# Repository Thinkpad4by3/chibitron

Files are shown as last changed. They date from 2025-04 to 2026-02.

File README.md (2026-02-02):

# chibitron
Chibitron is a Electrostatic CRT driver design built to solve the issues I've had with many of the other designs seen elsewhere on the internet. 

## Goals of the Project
* Fully Open Source HW/FW
* Compatible with as many CRTs as possible, as small as a 1EP1 or as big as a 7JP4.
* Single supply 12V input, with all necessary voltages generated on board.
* Onboard vector generation ability
* Ability to play Oscilloscope music with no extra equipment required.
* Built out of entirely currently stocked parts, using more common parts, when possible.

## Design of the system
Design of the system is designed around a two-part architecture. The main board provides all the required voltages to run the tube, mainly A2/A3/Focus control. This provides the main power for the electron gun, and can be adjusted from 400 - 2000V on mono-accelerator tubes (A2), or optionally boosted with another 400-2000V on post-deflection accelerator tubes(A2+A3). Total combined acceleration maxes out at 4kV which is sufficient for a very bright, very sharp image even on the most demanding of tubes. Filament voltage is supplied through a fully isolated 6.3V source, and focus is derived off A2 through a class-A amplfier. 

The 2nd board is the deflection board, which consists of all the required components to take any sort of vector control X/Y signal and amplify it to the +/- 150V required to move the beam around. This board is compatible with almost every type of ES-CRT, including single ended deflection type tubes. All plates are driven by 300Vpk-pk 500KHz bandwidth amplifiers, where gain/offset can be used to control picture size, and neutral voltage can set for astigmatism. Amplifiers are of a class-AB variety, and are closed loop for minimal distortion, and are powered by their own local bi-polar power supplies. 

Z-axis control is currently a WIP, but is going to be fully DC coupled. 

Currently, system has been tested with over a dozen CRTs, all showing clear and bright pictures with excellent clarity and brilliance. Tubes can be swapped in and out quickly with only minor tweaks to the board trimmer potentiometers. 

## CRT terminology:
Electrostatic CRT: Type of cathode-ray tube that uses capacitive plates to steer an electron beam with electric field instead of magnetic field  
H (Heater): Heater, used to heat cathode and cause thermionic emission of electrons  
K (Cathode): Cathode of tube, creates free electrons  
G1 (Grid): Grid control voltage, negatively biased from cathode to control electron beam current (and therefore beam brightness)  
A1 (Focus): Focus control voltage, used to create an electron lens, focusing beam to tight point on the screen surface  
A2 (Accelerator): Main anode for accelerating electrons towards screen   
Dx (Deflection): Plates numbered 1-4 for deflecting beam in X-Y direction. 1-2 are pair, 3-4 pair, with 3-4 usually being the more sensitive pair  
    -some tubes tie D1/D3/A2 together, known as single-ended deflection  
Astigmatism: generated through an offset between Dx neutral voltage and the A2 voltage.  
A3 (Post-deflection Accelerator): Anode inside the bell of the CRT which will accelerate electrons further after deflection. Used for increasing brightness without affecting deflection sensitivity.  

Phosphor: coating on the front of the tube that glows when struck with electrons. Comes in many varieties and colors; most commonly, green.   

Tube types: many US-made tubes follow a very simple naming scheme. For example, the 3BP1.  

3 -> 3" display  
B -> tube series (successor to 3AP1)  
P1 -> P1 phosphor designation, being a green medium persistence type.  

## Current files:
High Voltage supplies:
- main_supply: 1st generation 1000V
- main_supply_2: 1st generation 1500V + FILTERED
- main_supply_3: 2nd generation 2kV + 2kV 
- main_supply_3_revised: 2nd generation 2kV + 2kV BUG FIXED

Deflection:
- deflection_board: 1st generation ANALOG
- deflection_board_2: 2nd generation ANALOG
- deflection_board_3: 3rd generation DIGITAL 
- deflection_board_4: 3rd generation ANALOG
- deflection_board_5: 4th generation ANALOG + COMPOSITE

Check out the README under each folder for more information on the individual. 

## Currently tested working tubes:
3ASPx
3BPx
3JPx
3FPx
3RPx
5BPx
5UPx
5DEPx
5" unknown DuMont rectangular, medium base.
5XPx-B
7VPx

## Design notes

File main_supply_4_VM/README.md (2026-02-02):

## CRT High Voltage Gen.2 

## Status
- Completed, succeeded by main_supply_3_revised
- I would not recommend building this board

##  Design & Architecture 
The architecture was re-thought out from scratch over the previous supply. With the LM5180, they tended to work quite well, however they did have a bit of a major downside....regulation. Under extremely light load, the voltage would soar, and under very heavy load or it would tend to compensate by increasing the output voltage. Given the method of regulation is feedback sensing through the primary side, and high ratio step-up transformers are known for poor leakage inductance, the sensing ability of the converter could be quite poor at times. (See notes on Gen.1 V2 for more info on this)

(Mention the lack of a good method of adjustment due to the Rfb being a single resistor)

The new design uses an LM5155 and a far more conventional topology. The filament was powered through a TL431 regulated isolated flyback converter, and the A2/A3 generation was done through non-isolated ground referenced converters. A2 was referenced to ground, so the A2 supply generated the cathode potential at -400 - 2000V, and A3 was just the positive copy of A2. The main HV supplies use the NA5920-ALD, the only >1:10 ratio transformer available at the moment that is 

1) easily available
2) supports a >1000V HiPOT rating.

You might ask how I planned on getting 2000V out of a (barely) 1000V transformer. Well I'm going to use a voltage multiplier to just multiply the output by 3X. Seems like a good idea....cockroft-walton multipliers have been a proven choice of high-voltage generation for nearly a century. Well, we will get back to this in a bit. The exact topology follows the "boost mode style" found in a few LiDAR supplies and the like, which means that the charge pump caps are seperate from the filter caps, and the filter caps are larger. Otherwise, it operates the same way. Rough calculations say that 3x multiplier @ 2000V should keep the primary side at ~700V even at max voltage, should be fine for a 1500Vrms rated transformer. Primary side spiking thanks to the large 1:24 ratio would be kept at a meager 30V which would allow the choice of some more common low-voltage FETs.

Focus Amplifier was a somewhat odd design. As found on previous designs, the standard focus ladder stack was limiting for larger tubes. The highest voltage potentiometer easily available is 500V, and some larger tubes (7JP/7VP series) takes nearly 1kV on A1.

Revised from the LM5180, now uses the LM5155

designed to be SSR regulated, which was for better performance

higher voltage, more power

focus amplfiier was cursed, but it did work & iso-amp

moving the controls to the primary side for safety. 

opto feedback stuff 

NA5920-ALD transformer

## Troubleshooting & Bring-up 
lol SO MANY PROBLEMS

reversed problem with the opto-isolator.

missing soft-start

improperly UVLO spec'd resistors

- [ ] Wrong value resistors for the feedback chain for 400-2.1kV - A2
- [ ] Increase soft-start capacitance
- [ ] Transformer wrong: switch to Wurth 10:1 part
- [ ] MOSFET too low voltage: need >200V part
- [ ] Fix layout to not have GND overlapping underneath transformer
- [ ] Add RC filtering to A2,A3 + LC filtering to Filament
- [ ] Change TLV314 to TLV237, check >6.8V operation
- [ ] Fix the 20 ohm resistors in the VM’s to be in the correct spot
- [ ] Add soft start to filament supply 
- [ ] Capacitively couple feedback -> test this (only on A3)
- [ ] Change the RC filtering?? 2/2n + 100ohm & 1k R slope comp.
- [ ] Change connectors and remove focus amp from power supply side.
- [ ] Re-layout and silkscreen
- [ ] Add large input cap and filtering 
- [x] UVLO resistors configured incorrectly to disable on low-voltage - 10k lower
- [x] Fix diode on filament to be Schottky not HV rectifier
- [x] Add 220n + 2k resistor on A2
- [x] Add interlock if no power to op amp -> no A2 supply?
- [x] ADD POWER TO THE FUCKING AMPLIFIER FOR A2 FEEDBACK
- [x] Wrong sense resistor values for Current sense - 0.02ohm
- [x] Wrong value resistors for the feedback chain for 400-2.1kV - A3
- [x] Opto feedback wired up wrong - fix

## Learnings
really need to revisit how amplifiers works 

need to severely filter my output 

flybacks have sort of unregulated voltage

amp design seems good, continue with. 

8pF = slow feedback. will continue to monitor.

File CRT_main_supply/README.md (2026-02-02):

## CRT HV Supply Gen.1 V1

## Status
- Completed, succeeded by CRT_main_supply_2
- I would not recommend building this supply

##  Design & Architecture 
Uses the LM5180 Primary Side Regulated flyback controller. This was the easiest control to implement, given the original prototype was based on the LT8304-1 controller, which is the Analog Design variant of the same IC. The following reference design was used as my starting point for an inital prototype made a few months prior. This proved to be enough to get some life into a 3BP1, so I continued forward with that. I used the same 0399-T208 transformer, rated for 1KV output at up to 15mA, which was great for availability when I started this project. 

The use of a PSR regulator was great since it eliminated the need for any output sense such as a TL431 or large resistor ladder, and made it quite easy to slap a few of them on for the A2, Filament & Grid drive all with one converter. The supply was biased such that the ground reference could be moved around as needed, for experimentation purposes. 

Focus and Brightness are controlled through resistor dividers between A2 and Cathode.

Otherwise, the overall design was quite simple, and would be further revised later. 

Link: https://www.analog.com/en/resources/technical-articles/1000-v-output-no-opto-isolated-flyback-converter.html

## Troubleshooting & Bring-up 
Main problem with bring-up on this was down to the LM5180's undiagnosed requirement for RC filtering on the primary side. Due to the large step-up ratio and leakage inductance within the transformer, ringing under load would go far above the >85V rating of the internal FET. This is less of a problem when used in a 1:1 or lower ratio, where the reflected voltage is more...reasonable. A 220p + 100 ohm resistor as suggested by the LT8304 ended up being a good solution to fix this ringing, however not before nuking about 10 of those LM5180s. Atleast they're more reasonably priced than the LT8304. 

Other major issue was that the Filament was tied to the -1500V rail instead of floating off the cathode. For the purposes of most tubes, this is not a problem. Most CRTs have a H-H-K arrangement, which means the cathode is indirectly heated, and can generally float within +/- 125V of the cathode. G1-cutoff should be no more than 100V from the cathode, so this is generally fine. However, on some tubes, they are tied H-HK where either the tube is directly heated and the cathode is the heater, or the tube has the two connections internally tied to save pin-count. Either way, given the goal of maximum compatibility, mandating a tied HK was necessary.

Supply was able to light up a 3BP1, at this point I did not have many tubes to test with and this was the only tube I felt safe to test with. It did provide a decent picture, albeit a bit fuzzy. Some of this was due to unfiltered switching noise from the HV supplies. At this point, it just lit up with a dot since deflection_amp has not been brought up yet. It was however, good enough to get through deflection_amp developed, and therefore served its purpose.

## Learnings
LM5180 has some issues, regulation isn't wonderful and didn't like starting up the main filament supplies. Filament took nearly 6 seconds to get to full voltage, and another 10 seconds for the tube to start conducting. 

Ground reference can be set to GND -> A2 is optimal.

H-HK filament biasing required.

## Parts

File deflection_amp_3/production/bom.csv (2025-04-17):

Designator | Footprint | Quantity | Value | LCSC Part #
C1, C11, C12, C2, C3, C4 | 0805 | 6 | 10u
C10, C9 | 0805 | 2 | 0.22u
C13, C14, C15 | 1812 | 3 | 1u
C16, C19, C20, C22, C24, C25, C26, C27, C28, C29, C30, C31, C44, C45, C46, C47 | 0603 | 16 | 0.1u
C17, C18 | 0603 | 2 | 15p
C21, C23, C7, C8 | 0603 | 4 | 1u
C32, C35, C38, C41 | 0603 | 4 | 2p
C33, C36, C39, C42, C5, C6 | 0603 | 6 | 1n
C34, C37, C40, C43 | 0603 | 4 | 39p
D1, D2, D3 | D_SOD-123F | 3 | D
D4, D5, D6, D9 | 0603 | 4 | LED
D7 | D_SOD-123 | 1 | 4.1V
D8 | D_SOD-123 | 1 | 11V
F1 | 0805 | 1 | 2A
J1 | USB_C_Receptacle_Palconn_UTC16-G | 1 | USB_C_Receptacle_USB2.0_14P
J2 | Molex_KK-396_5273-02A_1x02_P3.96mm_Vertical | 1 | POWER INPUT
J3 | PinHeader_1x03_P2.54mm_Vertical | 1 | OFFSET REFERENCE
J4 | Molex_KK-396_5273-05A_1x05_P3.96mm_Vertical | 1 | DEFLECTION OUT
L1, L2 | L_APV_APH0420 | 2 | 10u
Q1, Q11, Q14, Q16, Q17, Q19, Q22, Q24, Q25, Q27, Q3, Q30, Q32, Q6, Q8, Q9 | SOT-23 | 16 | FMMT458TA
Q10, Q12, Q13, Q15, Q18, Q2, Q20, Q21, Q23, Q26, Q28, Q29, Q31, Q4, Q5, Q7 | SOT-23 | 16 | FMMT558TA
R1, R2 | 0603 | 2 | 5.1k
R10, R9 | 0603 | 2 | 107k
R11 | 0603 | 1 | 14.3k
R12, R13, R3, R5, R8, R81, R82 | 0603 | 7 | 100k
R14 | 0603 | 1 | 162k
R15, R16 | 1206 | 2 | 22
R17, R19 | 1206 | 2 | 1Meg
R18 | 1206 | 1 | 12.7k
R20 | 1206 | 1 | 6.3k
R21, R25, R29, R30, R42, R43, R55, R56, R68, R69 | 0603 | 10 | 10k
R22, R84 | 0603 | 2 | 1k
R23, R24 | 0603 | 2 | 27.4
R26, R27, R32, R33, R35, R36, R37, R38, R39, R40, R45, R46, R48, R49, R50, R51, R52, R53, R58, R59, R61, R62, R63, R64, R65, R66, R71, R72, R74, R75, R76, R77 | 1206 | 32 | 2k
R28, R41, R54, R67 | 1206 | 4 | 200k
R31, R34, R44, R47, R57, R60, R70, R73 | 1206 | 8 | 5k
R4 | 0603 | 1 | 19.7k
R6, R7 | 0603 | 2 | 84.5k
R78, R79, R80, R83 | 0603 | 4 | 220
RV1, RV2, RV3, RV4, RV5 | Potentiometer_Bourns_3296W_Vertical | 5 | 100k
SW1 | SW_SPST_Omron_B3FS-101xP | 1 | RESET
SW2 | SW_SPST_Omron_B3FS-101xP | 1 | PROG
TP1 | TestPoint_Pad_1.0x1.0mm | 1 | SWCLK
TP2 | TestPoint_Pad_1.0x1.0mm | 1 | SWD
TP3 | TestPoint_Pad_1.0x1.0mm | 1 | GND
U1, U2 | SOT-23-5 | 2 | AP2205-ADJ
U10, U11, U12, U9 | TSOT-23-6 | 4 | LMH6639
U3, U4 | Analog_MSOP-12-16-1EP_3x4.039mm_P0.5mm_EP1.651x2.845mm | 2 | LT8365
U5 | SOIC-8_5.3x5.3mm_P1.27mm | 1 | W25Q128JVS
U6 | QFN-56-1EP_7x7mm_P0.4mm_EP3.2x3.2mm | 1 | RP2040
U7, U8 | SOIC127P599X175-8N | 2 | MCP4822
Y1 | Crystal_SMD_3225-4Pin_3.2x2.5mm | 1 | ABM8-272-T3

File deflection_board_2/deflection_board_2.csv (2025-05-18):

Reference | Value | Datasheet | Footprint | Qty | DNP
C1,C10,C15,C20 | 68p | QSCP251Q390G1GV001T | Capacitor_SMD:C_0603_1608Metric_Pad1.08x0.95mm_HandSolder | 4
C2,C9,C14,C19 | 2p | GRM1885C1H8R0DA01D | Capacitor_SMD:C_0603_1608Metric_Pad1.08x0.95mm_HandSolder | 4
C3,C4,C5,C6,C7,C8,C11,C12,C13,C16,C17,C18 | 0.1u | CL10E104KC8VPNC | Capacitor_SMD:C_0603_1608Metric_Pad1.08x0.95mm_HandSolder | 12
C21,C22 | 0.1u | CL10E104KC8VPNC | Capacitor_SMD:C_0603_1608Metric | 2
C23,C24 | 1u | C1608X7R1C105K080DC | Capacitor_SMD:C_0603_1608Metric | 2
C25,C26,C27,C30 | 10u | ~CL10A106KQ8NNNC | Capacitor_SMD:C_0603_1608Metric | 4
J1,J2,J3,J4 | Conn_01x03_Pin | ~ | Connector_PinHeader_2.54mm:PinHeader_1x03_P2.54mm_Vertical | 4
J5 | MAIN BOARD CONNECTOR | 0009652098 | Connector_Molex:Molex_KK-396_5273-09A_1x09_P3.96mm_Vertical | 1
J6,J7 | RCJ-011 | RCJ-011 | RCJ-011:CUI_RCJ-011 | 2
L1 | L | NRS4018T100MDGJ | Inductor_SMD:L_APV_ANR4018 | 1
Q1,Q2,Q7,Q8,Q9,Q11,Q14,Q16,Q17,Q19,Q22,Q24,Q25,Q27,Q30,Q32 | FMMT458TA | FMMT458TA | Package_TO_SOT_SMD:SOT-23 | 16
Q3,Q4,Q5,Q6,Q10,Q12,Q13,Q15,Q18,Q20,Q21,Q23,Q26,Q28,Q29,Q31 | FMMT558TA | FMMT558TA | Package_TO_SOT_SMD:SOT-23 | 16
R1,R11,R21,R31,R41,R42,R43,R44 | 2k | RMCF1206FT2K00 | Resistor_SMD:R_1206_3216Metric_Pad1.30x1.75mm_HandSolder | 8
R2,R12,R22,R32 | 200k | ERA-8AEB204V | Resistor_SMD:R_1206_3216Metric_Pad1.30x1.75mm_HandSolder | 4
R3,R9,R10,R16,R19,R20,R26,R29,R30,R36,R39,R40 | 1k | RNCP1206FTD1K00 | Resistor_SMD:R_1206_3216Metric_Pad1.30x1.75mm_HandSolder | 12
R4,R17,R27,R37 | 100 | ERJ-8ENF1000V | Resistor_SMD:R_1206_3216Metric_Pad1.30x1.75mm_HandSolder | 4
R5,R6,R13,R14,R23,R24,R33,R34,R59,R63 | 10k | RMCF0603JT10K0 | Resistor_SMD:R_0603_1608Metric_Pad0.98x0.95mm_HandSolder | 10
R7,R8,R15,R18,R25,R28,R35,R38 | 5k | RT1206FRE075KL | Resistor_SMD:R_1206_3216Metric_Pad1.30x1.75mm_HandSolder | 8
R45,R46 | 6.2k | RC0603JR-076K2L | Resistor_SMD:R_0603_1608Metric | 2
R47,R48 | 3.7k | RN73H1JTTD3701B25 | Resistor_SMD:R_0603_1608Metric | 2
R49 | 30.3k | RMCF0805FT30K0 | Resistor_SMD:R_0805_2012Metric | 1
R50,R52 | 10k | RR1220P-103-D | Resistor_SMD:R_0805_2012Metric | 2
R51 | 70.6k | RNCF0805BKE70K6 | Resistor_SMD:R_0805_2012Metric | 1
R53,R54 | 10k | RMCF0603JT10K0 | Resistor_SMD:R_0603_1608Metric | 2
R61,R65,R67,R69 | 1k | ERJ-3EKF1001V | Resistor_SMD:R_0603_1608Metric_Pad0.98x0.95mm_HandSolder | 4
R62,R66,R68,R70 | 2.2k | CRGCQ0603F2K2 | Resistor_SMD:R_0603_1608Metric_Pad0.98x0.95mm_HandSolder | 4
RV6,RV8 | 5k | 3296W-1-502LF | Potentiometer_THT:Potentiometer_Bourns_3296W_Vertical | 2
RV7,RV9 | 47k | 3296W-1-473LF | Potentiometer_THT:Potentiometer_Bourns_3296W_Vertical | 2
U1,U2,U3,U4 | LMH6639 | LMH6639 | Package_TO_SOT_SMD:TSOT-23-6 | 4
U5,U8 | AP2204K-ADJ | AP2204K-ADJ | Package_TO_SOT_SMD:SOT-23-5 | 2
U6,U7 | LMH6551MA | LMH6551MA | Package_SO:SOIC-8_3.9x4.9mm_P1.27mm | 2

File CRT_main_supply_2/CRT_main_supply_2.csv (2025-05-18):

Reference | Value | Datasheet | Footprint | Qty | DNP
C1,C9,C19,C20,C29 | 47n | C0805C473K1RECAUTO | Capacitor_SMD:C_0805_2012Metric | 5
C2,C11,C24,C31 | 270p | C0805C271J5GACTU | Capacitor_SMD:C_0805_2012Metric | 4
C3,C4,C5,C6,C7,C8,C10,C18,C23,C28,C30 | 10u | CL21A106KOQNNNG | Capacitor_SMD:C_0805_2012Metric | 11
C12,C13,C14 | 2.2u | CL31B225KCHSNNE | Capacitor_SMD:C_1206_3216Metric | 3
C15,C16,C17,C22,C25,C26,C27 | 0.22u | C4532X7T2J224K200KC | Capacitor_SMD:C_1812_4532Metric | 7
C21,C32 | 0.033u | 2225GC333KAT1A | Capacitor_SMD:C_2225_5664Metric | 2
D1,D2,D3,D4,D6,D7 | 100V | SMD110PL-TP | Diode_SMD:D_SOD-123F | 6
D5,D8,D9,D10 | 800V | CMMR1U-08 | Diode_SMD:D_SOD-123F | 4
D11 | LED | RED 0805 | LED_SMD:LED_0805_2012Metric | 1
F1 | 3A | C1F 3 | Fuse:Fuse_1206_3216Metric | 1
J1,J2,J7,J8 | ENABLE_OVERRIDE | 2P JUMPER | Connector_PinHeader_2.54mm:PinHeader_1x02_P2.54mm_Vertical | 4
J3 | Conn_01x09_Pin | 0009652098 | Connector_Molex:Molex_KK-396_5273-09A_1x09_P3.96mm_Vertical | 1
J4 | ENABLE_PORT | 0009652068 | Connector_Molex:Molex_KK-396_5273-06A_1x06_P3.96mm_Vertical | 1
J5,J6 | Conn_01x05_Pin | 0009652058 | Connector_Molex:Molex_KK-396_5273-05A_1x05_P3.96mm_Vertical | 2
J9 | POWER INPUT | 0009652028 | Connector_Molex:Molex_KK-396_5273-02A_1x02_P3.96mm_Vertical | 1
J10 | Conn_01x06_Pin | 0009652068 | Connector_Molex:Molex_KK-396_5273-06A_1x06_P3.96mm_Vertical | 1
L1,L2 | 10uH | NRS4018T100MDGJ | Inductor_SMD:L_APV_ANR4018 | 2
R1 | 160k | RC0805FR-07160KL | Resistor_SMD:R_0805_2012Metric | 1
R2,R4,R5,R7,R8,R16,R17,R30,R31 | 12.1k | RMCF0603FT12K1 | Resistor_SMD:R_0603_1608Metric | 9
R3,R9,R26,R32 | 100 | ERJ-8ENF1000V | Resistor_SMD:R_1206_3216Metric | 4
R6 | 1.6k | ERJ-6GEYJ162V | Resistor_SMD:R_0805_2012Metric | 1
R10 | 250k | RNCF0805BTE250K | Resistor_SMD:R_0805_2012Metric | 1
R11 | 100k | RC0805FR-07100KL | Resistor_SMD:R_0805_2012Metric | 1
R12,R18,R20,R29 | 2.2k | CRG0805F2K2 | Resistor_SMD:R_0805_2012Metric | 4
R13 | 220 | RMCF1206FT220R | Resistor_SMD:R_1206_3216Metric | 1
R14 | 698k | RC0805FR-0747KL | Resistor_SMD:R_0805_2012Metric | 1
R15 | 47k | RC0805FR-07698KL | Resistor_SMD:R_0805_2012Metric | 1
R19 | 249k | RC1206FR-07249KL | Resistor_SMD:R_1206_3216Metric | 1
R21,R22,R23,R24,R25,R33 | 500k | CRMA1206AF500KFKEF | Resistor_SMD:R_1206_3216Metric | 6
R27 | 324k | RC0805FR-07324KL | Resistor_SMD:R_0805_2012Metric | 1
R28 | 10k | RC1206FR-0710KL | Resistor_SMD:R_1206_3216Metric | 1
RV1,RV3 | 500k | 3296W-1-504LF | Potentiometer_THT:Potentiometer_Bourns_3296W_Vertical | 2
RV2 | 100k | 3296W-1-104LF | Potentiometer_THT:Potentiometer_Bourns_3296W_Vertical | 1
T1 | 0399-T208 | 0399-T208 | 0399-T208:0399-T208 | 1
T2 | YA9033-ALD | YA9033-ALD | YA9033-ALD:XFMR_YA9033-ALD | 1
T3 | YA9037-ALD | YA9037-ALD | YA9033-ALD:XFMR_YA9033-ALD | 1
T4 | 13324-T087 | 13324-T087 | 13324-T087:13324-T087 | 1
U1,U3,U6,U7 | LM5180QNGURQ1 | LM5180NGUR | LM5180:SON80P400X400X80-9N | 4
U2 | TLV76701DRVx | TLV76701 | Package_SON:WSON-6-1EP_2x2mm_P0.65mm_EP1x1.6mm_ThermalVias | 1
U4 | LR12K4-G | LR12K4-G | Package_TO_SOT_SMD:TO-252-2 | 1
U5 | LR8K4-G | LR8K4-G | Package_TO_SOT_SMD:TO-252-2 | 1

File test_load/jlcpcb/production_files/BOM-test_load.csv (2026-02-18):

Comment | Designator | Footprint | LCSC | Quantity
100k | R1,R10,R100,R11,R12,R13,R14,R15,R16,R17,R18,R19,R2,R20,R21,R22,R23,R24,R25,R26,R27,R28,R29,R3,R30,R31,R32,R33,R34,R35,R36,R37,R38,R39,R4,R40,R41,R42,R43,R44,R45,R46,R47,R48,R49,R5,R50,R51,R52,R53,R54,R55,R56,R57,R58,R59,R6,R60,R61,R62,R63,R64,R65,R66,R67,R68,R69,R7,R70,R71,R72,R73,R74,R75,R76,R77,R78,R79,R8,R80,R81,R82,R83,R84,R85,R86,R87,R88,R89,R9,R90,R91,R92,R93,R94,R95,R96,R97,R98,R99 | R_1206_3216Metric | C17927 | 100

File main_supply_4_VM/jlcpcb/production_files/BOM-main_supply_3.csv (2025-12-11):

Comment | Designator | Footprint | LCSC | Quantity
220n | C17,C19,C23,C4,C6,C8 | C_2220_5750Metric | C1021535 | 6
100n | C16,C18,C7,C9 | C_1812_4532Metric | C106147 | 4
A3_EN | J2,J5,J6,J8 | PinHeader_1x02_P2.54mm_Vertical | C124375 | 4
CSD19537Q3 | Q1,Q2,Q3 | VSON-8_3.3x3.3mm_P0.65mm_NexFET | C134143 | 3
100n | C24,C31,C44,C45,C46,C47,C5,C50,C51,C58 | C_0603_1608Metric | C14663 | 10
100p | C15,C53 | C_0603_1608Metric | C14858 | 2
1u | C11,C26,C39,C57 | C_0603_1608Metric | C15849 | 4
10u | C2,C21,C22,C3,C32,C33,C35,C36,C42,C43,C48,C49 | C_0805_2012Metric | C15850 | 12
1n | C52,C55,C56 | C_0603_1608Metric | C1588 | 3
220p | C1,C12,C20,C27,C30 | C_0603_1608Metric | C1603 | 5
470p | C10,C25,C38 | C_0603_1608Metric | C1620 | 3
47n | C13,C28,C41 | C_0603_1608Metric | C1622 | 3
100k | R71 | R_1206_3216Metric | C17900 | 1
1Meg | R13,R14,R16,R17,R18,R19,R20,R21,R22,R35,R37,R38,R39,R40,R41,R42,R43,R44,R45,R61,R62,R63,R64,R65,R66,R70,R74 | R_1206_3216Metric | C17927 | 27
20 | R24,R25,R28,R5,R6,R9 | R_1206_3216Metric | C17955 | 6
Fuse | F1 | Fuse_0805_2012Metric | C1972452 | 1
TLV314QDBVR | U10,U11,U2 | SOT-23-5 | C2058787 | 3
220n | C37,C40 | C_0603_1608Metric | C21120 | 2
22n | C14,C29 | C_0603_1608Metric | C21122 | 2
0 | R31,R53,R7 | R_0603_1608Metric | C21189 | 3
1k | R50,R54,R55,R57 | R_0603_1608Metric | C21190 | 4
100 | R30,R4,R48 | R_0603_1608Metric | C22775 | 3
LED | D1,D14,D16,D18,D8 | LED_0603_1608Metric | C2290 | 5
20 | R32,R56,R8 | R_0603_1608Metric | C22950 | 3
2k | R10,R33,R58 | R_0603_1608Metric | C22975 | 3
3.9k | R1,R26 | R_0603_1608Metric | C23018 | 2
5k | R52,R73 | R_0603_1608Metric | C23046 | 2
4.7k | R23 | R_0603_1608Metric | C23162 | 1
470 | R15,R46 | R_0603_1608Metric | C23179 | 2
50k | R2,R27,R29,R3,R47,R49,R60 | R_0603_1608Metric | C23184 | 7
6.8k | R67 | R_0603_1608Metric | C23212 | 1
Conn_01x02_Pin | J1 | Molex_KK-396_5273-02A_1x02_P3.96mm_Vertical | C239393 | 1
FIL CAT FOCUS | J7 | Molex_KK-396_5273-05A_1x05_P3.96mm_Vertical | C239396 | 1
100k | R12,R36,R68 | R_0603_1608Metric | C25803 | 3
10k | R69,R72,R75,R76,R77 | R_0603_1608Metric | C25804 | 5
AP2204K-5.0 | U7,U8 | SOT-23-5 | C2928719 | 2
STN0214 | Q4 | SOT-223-3_TabPin2 | C2969811 | 1
22k | R11,R34 | R_0603_1608Metric | C31850 | 2
100u | C34 | CP_Elec_6.3x7.7 | C3338 | 1
20k | R59 | R_0603_1608Metric | C4184 | 1
33k | R51 | R_0603_1608Metric | C4216 | 1
1Meg | RV1 | Potentiometer_Bourns_3296W_Vertical | C48084 | 1
PC817 | U4 | DIP-4_W7.62mm | C5350 | 1
D | D10,D11,D12,D13,D17,D2,D3,D5,D6,D7,D9 | D_SMA | C5387 | 11
LM5155DSSR | U1,U3,U5 | IC_LM5155DSSR | C545416 | 3
4.7k | RV2,RV3,RV4,RV5 | Potentiometer_Bourns_3296W_Vertical | C60620 | 4
TL431DBZ | U6 | SOT-23 | C6971 | 1
0.002 | RS1,RS2,RS3 | R_1206_3216Metric | C728295 | 3
AMC1311 | U9 | SOIC-8_7.5x5.85mm_P1.27mm | C783598 | 1
A3 | J3,J4 | PinHeader_1x01_P2.54mm_Vertical | C81276 | 2
1n | C54 | C_1206_3216Metric | C9196 | 1
YA9033-ALD | T3 | XFMR_YA9033-ALD |  | 1
~ | T1 | NA5920-AL |  | 1
~ | T2 | NA5920-AL |  | 1

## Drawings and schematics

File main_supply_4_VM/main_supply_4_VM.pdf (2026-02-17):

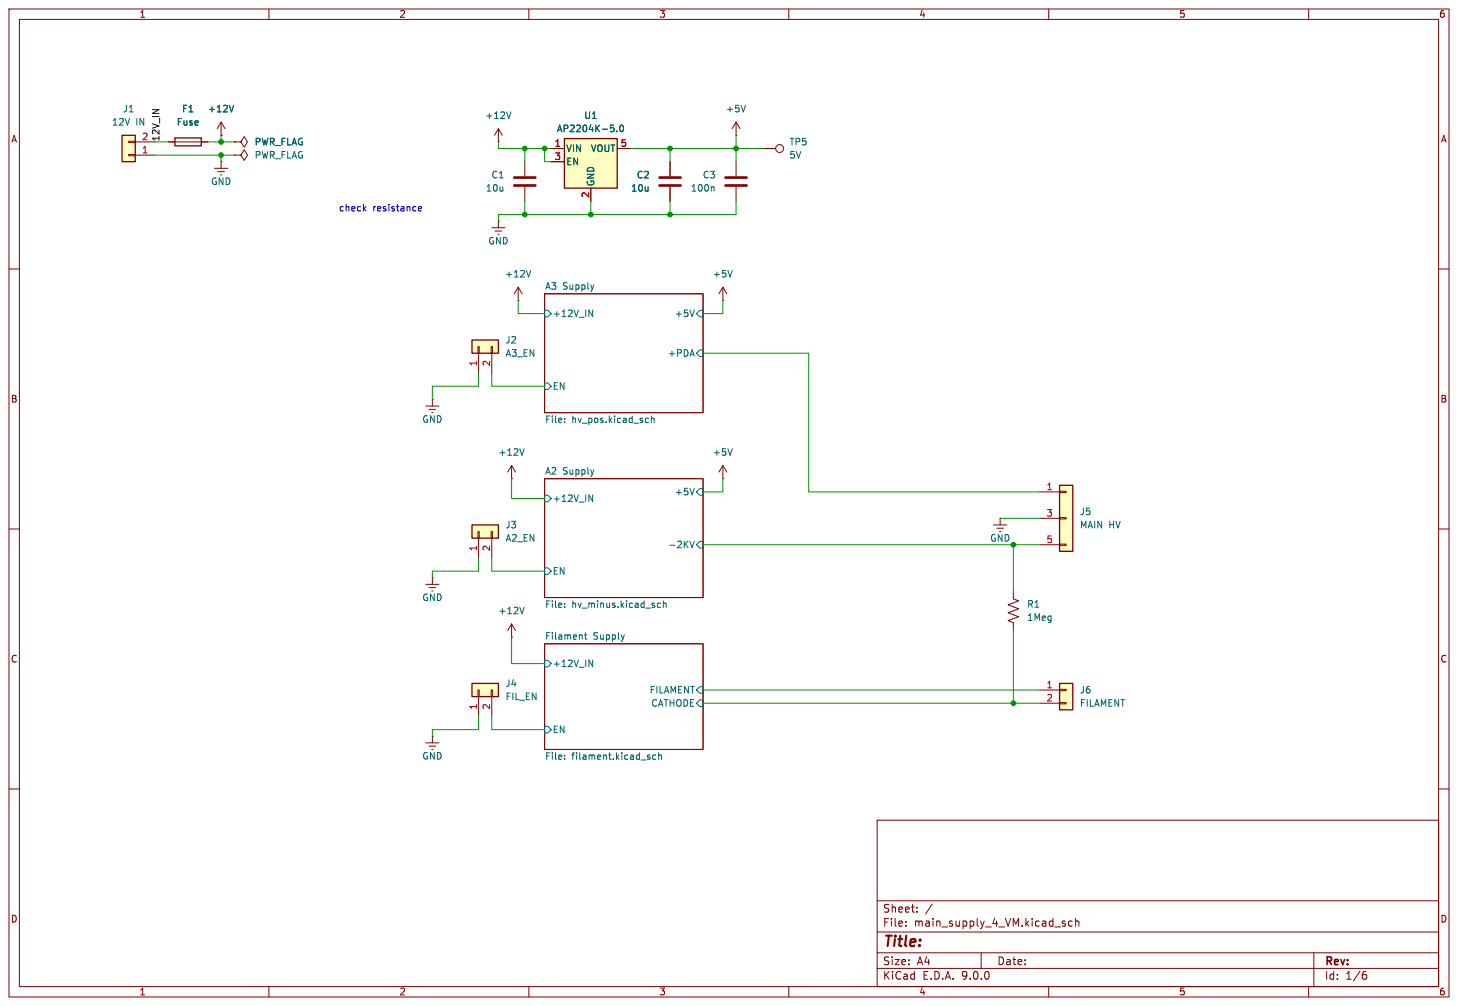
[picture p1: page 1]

Id: 1/6 Title: File: main_supply_4_VM.kicad_sch Sheet: / +12V_IN

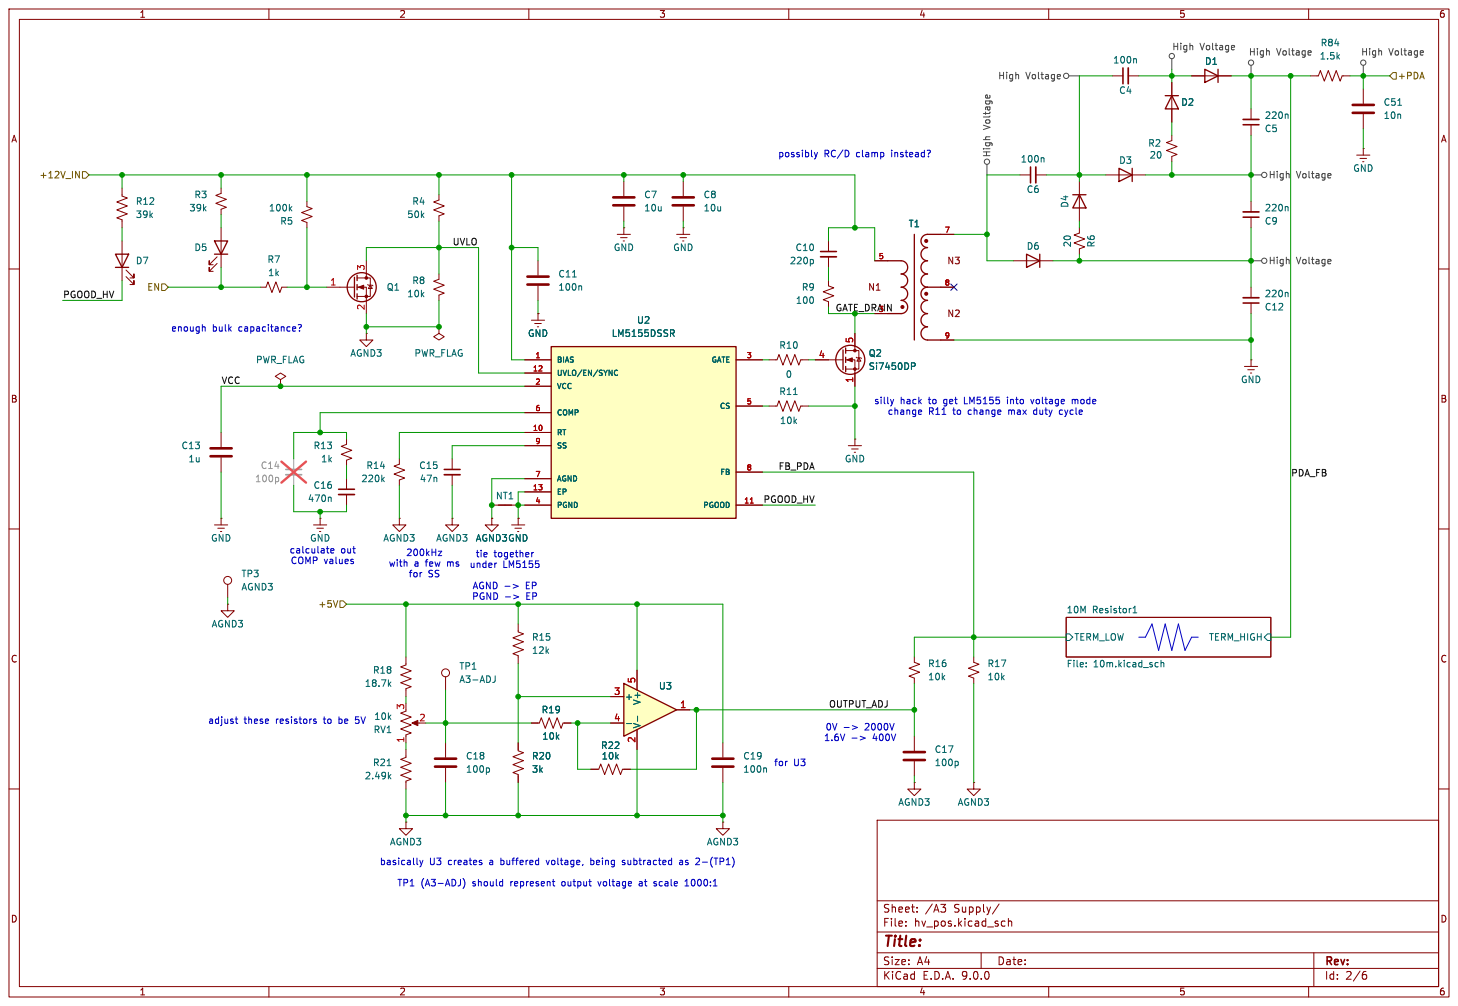
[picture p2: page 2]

High Voltage

silly hack to get LM5155 into voltage mode
change R11 to change max duty cycle

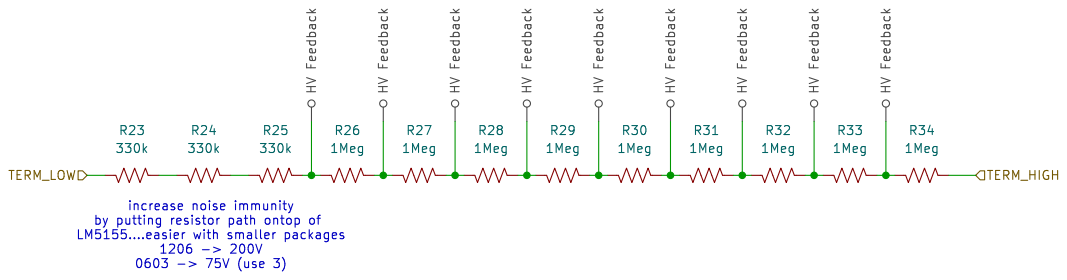
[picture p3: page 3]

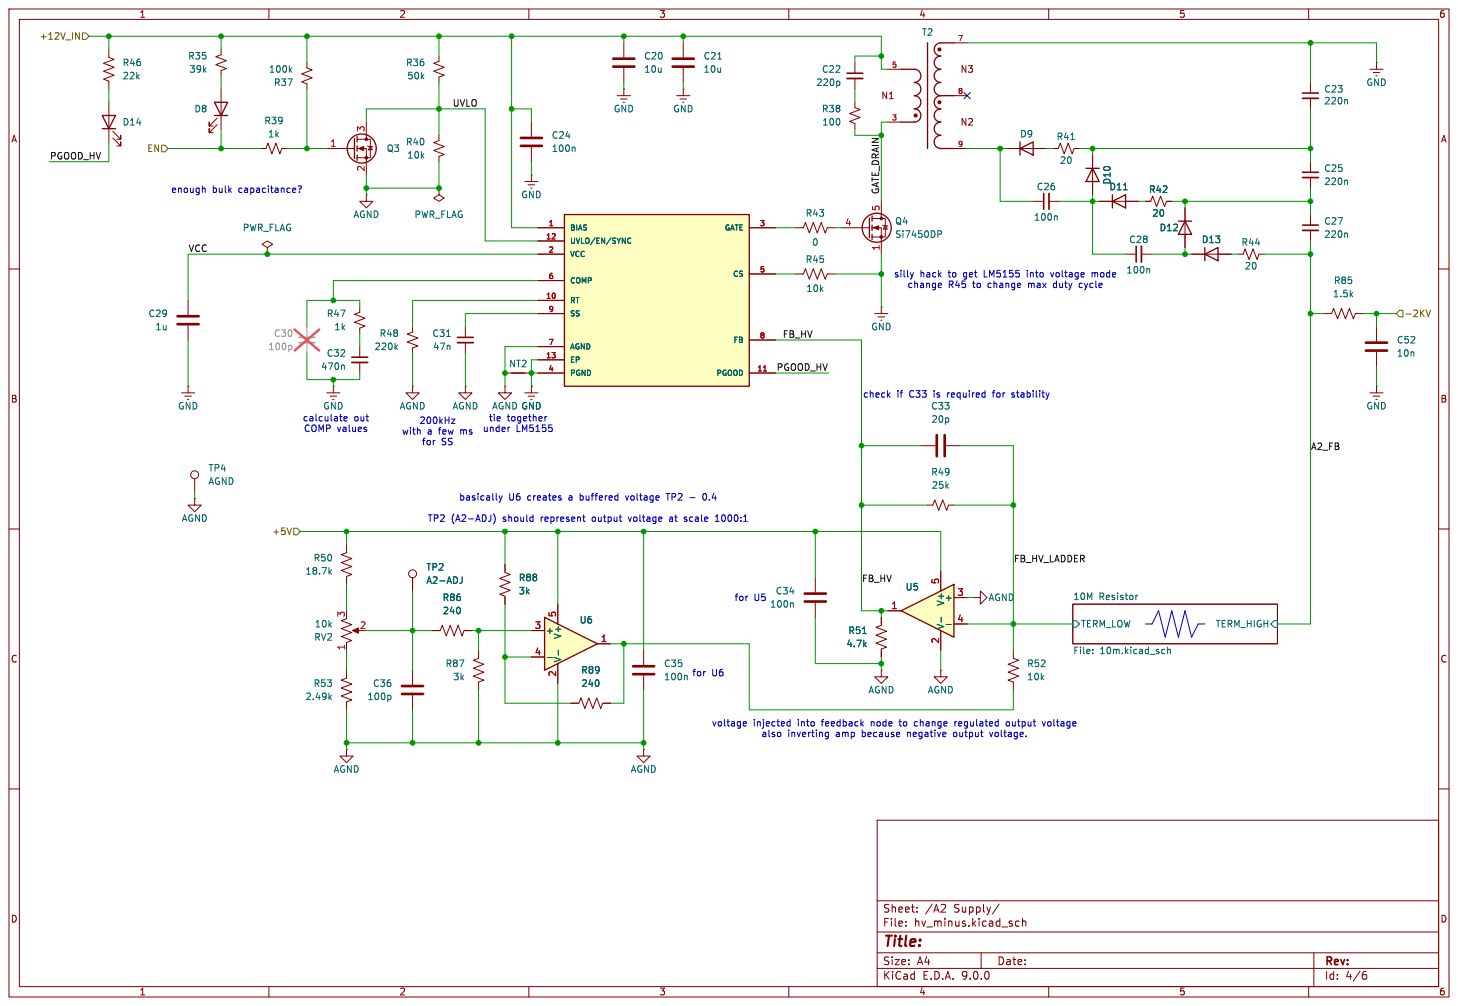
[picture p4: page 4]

silly hack to get LM5155 into voltage mode
change R45 to change max duty cycle

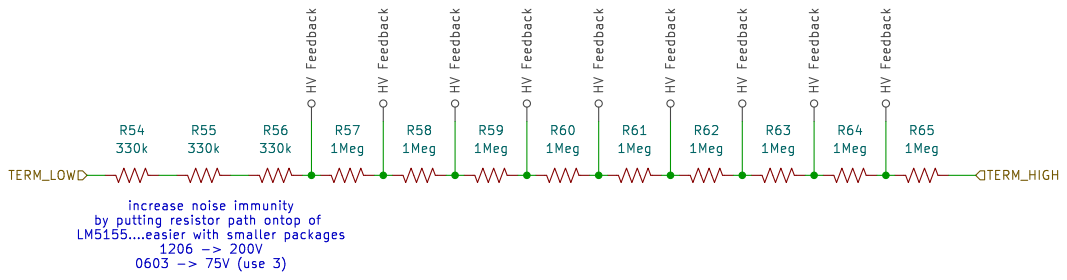
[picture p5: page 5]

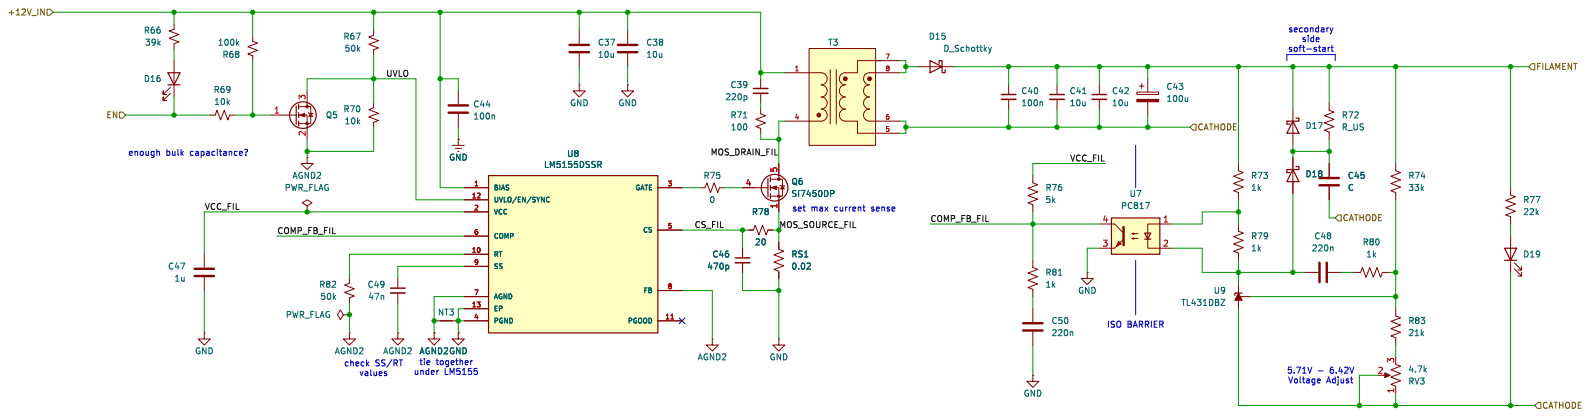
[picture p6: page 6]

soft-start check SS/RT

set max current sense

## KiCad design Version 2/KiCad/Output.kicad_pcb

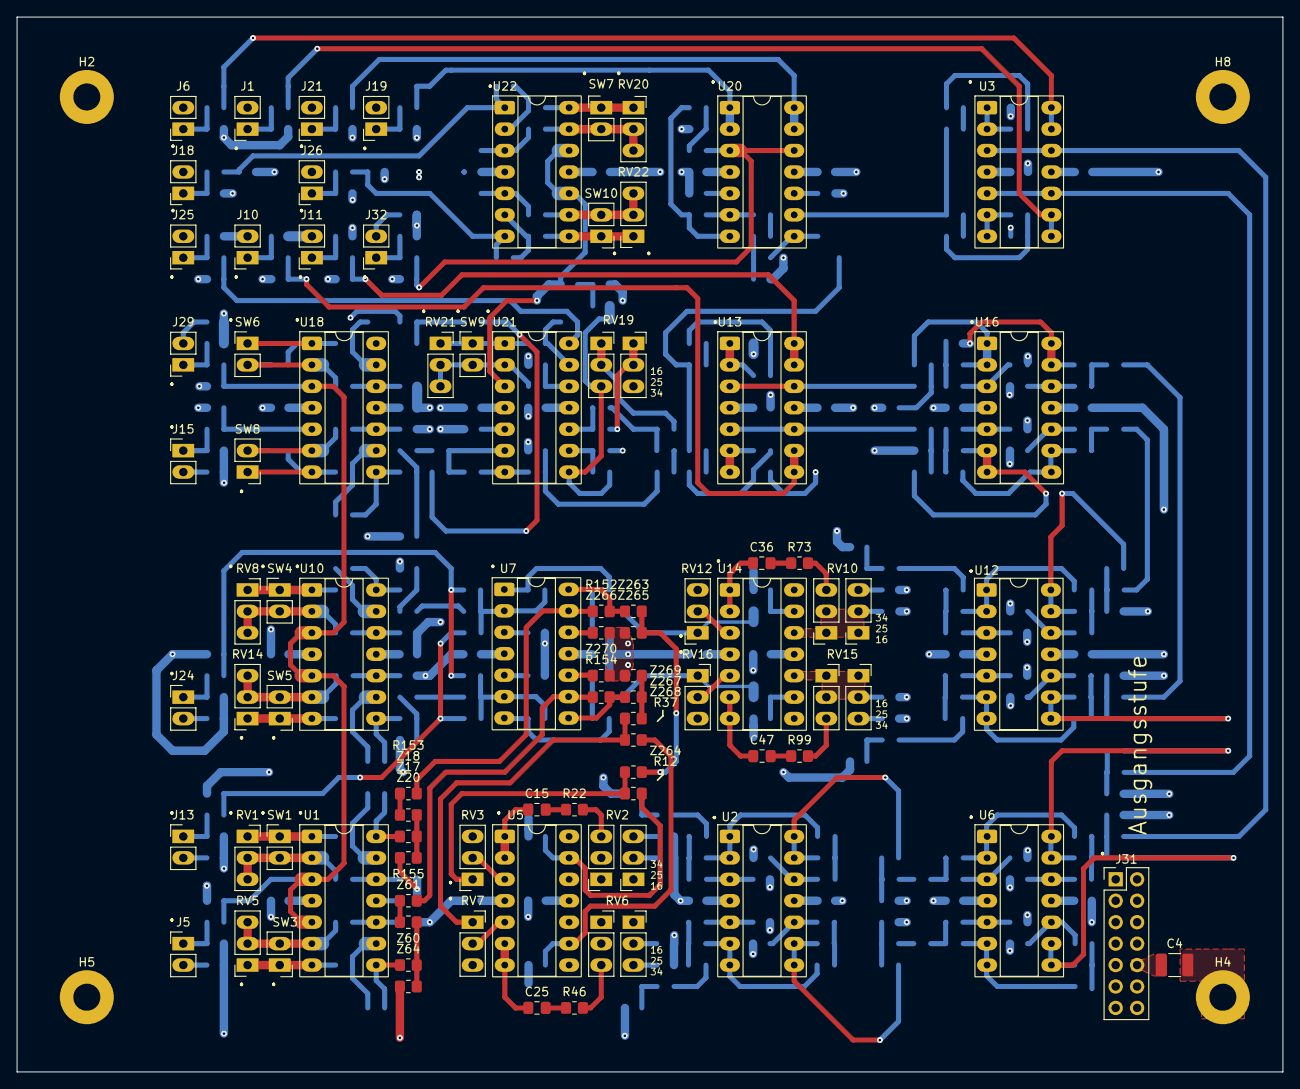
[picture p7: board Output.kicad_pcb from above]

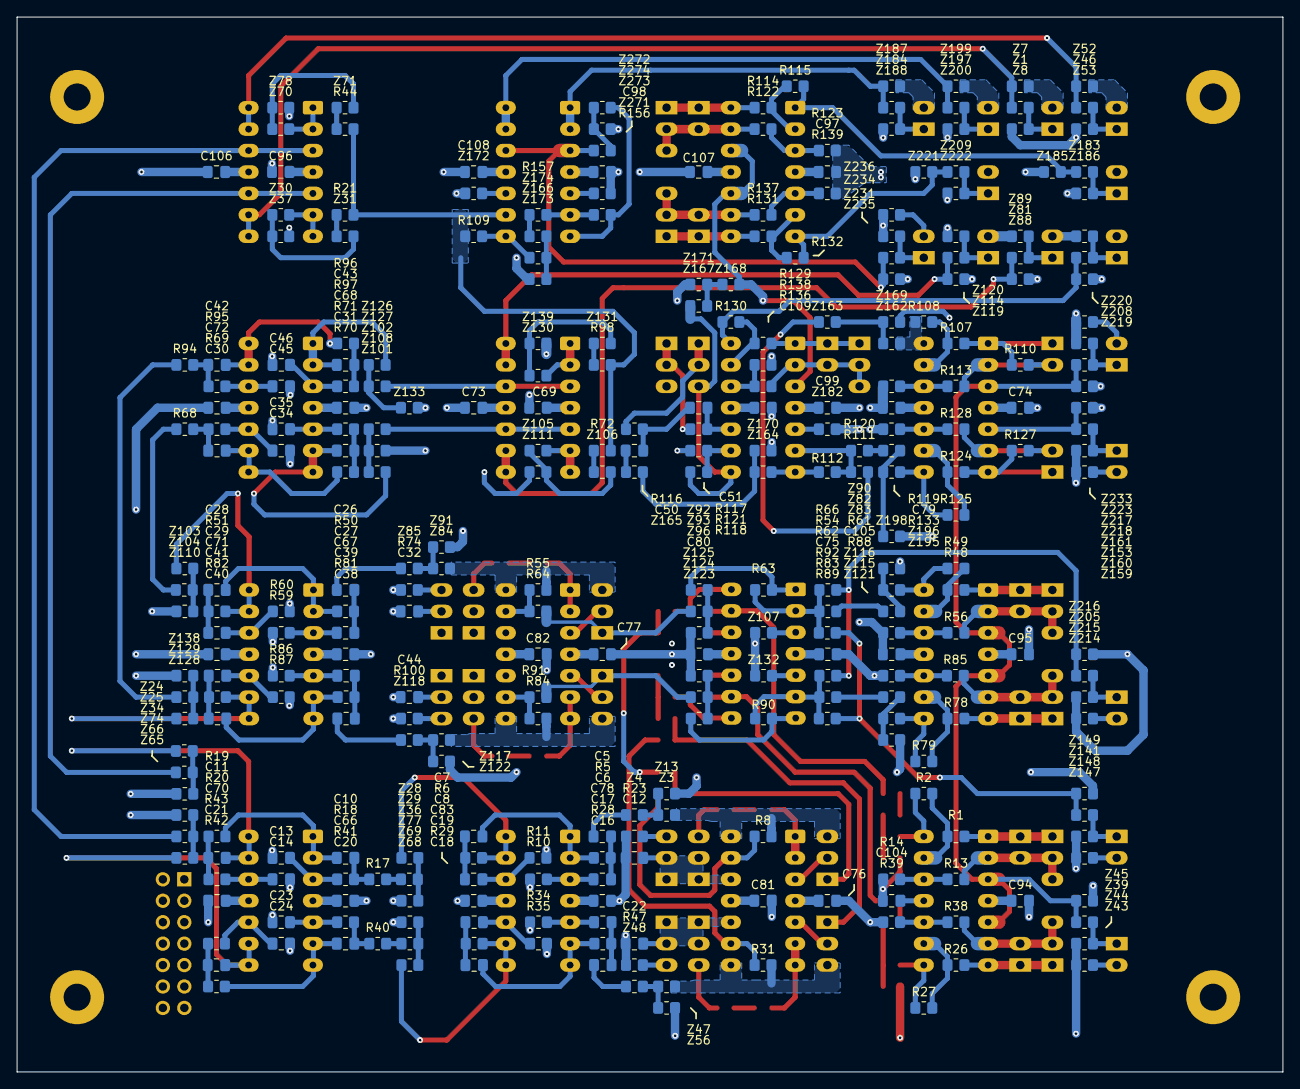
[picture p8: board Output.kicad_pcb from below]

Board: 4 copper layers, 150.0 x 125.0 mm, 393 parts (304 on the bottom side), 253 nets.

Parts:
C4: 10n; C_1210_3225Metric_Pad1.33x2.70mm_HandSolder
C5, C6, C7, C8, C10, C11, C13, C14, C16, C17, C18, C19, C20, C21, C23, C24, C26, C27, C28, C29, C30, C31, C34, C35, C38, C39, C40, C41, C42, C43, C45, C46: 130n; C_0805_2012Metric_Pad1.18x1.45mm_HandSolder
C12, C22, C32, C44: 470p; C_0805_2012Metric_Pad1.18x1.45mm_HandSolder
C15, C25, C36, C47: 3n; C_0805_2012Metric_Pad1.18x1.45mm_HandSolder
C50, C51: 6n8; C_0805_2012Metric_Pad1.18x1.45mm_HandSolder
C66, C67, C68, C69, C70, C71, C72, C73, C74, C75, C76, C77, C78, C79, C80, C81, C82, C83, C94, C95, C96, C97, C98, C99, C104, C105, C106, C107, C108, C109: 100n; C_0805_2012Metric_Pad1.18x1.45mm_HandSolder
H2, H5, H8: MountingHole; MountingHole_3.2mm_M3_Pad
H4: MountingHole_Pad; MountingHole_3.2mm_M3_Pad
J1: Bass_Out; PinSocket_1x02_P2.54mm_Vertical_LongPads
J5: Phono/Line_In; PinHeader_1x02_P2.54mm_Vertical_LongPads
J6: Kick_Out; PinSocket_1x02_P2.54mm_Vertical_LongPads
J10: Mid_Out; PinSocket_1x02_P2.54mm_Vertical_LongPads
J11: High_Out; PinSocket_1x02_P2.54mm_Vertical_LongPads
J13, J15, J24: Mic_Effekt_In; PinHeader_1x02_P2.54mm_Vertical_LongPads
J18: AUX_Send_1; PinSocket_1x02_P2.54mm_Vertical_LongPads
J19: Line_Out_L; PinSocket_1x02_P2.54mm_Vertical_LongPads
J21: Line_Out_R; PinSocket_1x02_P2.54mm_Vertical_LongPads
J25: AUX_Send_3; PinSocket_1x02_P2.54mm_Vertical_LongPads
J26: AUX_Send_2; PinSocket_1x02_P2.54mm_Vertical_LongPads
J29, J32: Pegel_Out; PinSocket_1x02_P2.54mm_Vertical_LongPads
J31: Conn_02x07_Odd_Even; PinHeader_2x07_P2.54mm_Vertical
R1, R26, R48, R78, R114, R129, R131: 4k7; R_0805_2012Metric_Pad1.20x1.40mm_HandSolder
R2, R21, R27, R44, R49, R54, R62, R63, R66, R72, R79, R83, R89, R90, R92, R98, R107, R108, R109, R111, R112, R115, R116, R117, R118, R120, R121, R124, R125, R130, R132, R152, R153, R154, R155, R156, R157: 10k; R_0805_2012Metric_Pad1.20x1.40mm_HandSolder
R5, R6, R10, R11, R22, R23, R28, R29, R34, R35, R46, R47, R50, R51, R59, R60, R73, R74, R81, R82, R86, R87, R99, R100: 6k8; R_0805_2012Metric_Pad1.20x1.40mm_HandSolder
R8, R12, R17, R18, R19, R20, R31, R37, R40, R41, R42, R43, R55, R64, R68, R69, R70, R71, R84, R91, R94, R95, R96, R97: 22k; R_0805_2012Metric_Pad1.20x1.40mm_HandSolder
R13, R38, R56, R85, R122, R136, R137: 470R; R_0805_2012Metric_Pad1.20x1.40mm_HandSolder
R14, R39, R61, R88, R123, R138, R139: 1k; R_0805_2012Metric_Pad1.20x1.40mm_HandSolder
R110, R113, R119, R127, R128, R133: 5k; R_0805_2012Metric_Pad1.20x1.40mm_HandSolder
RV1, RV5, RV8, RV14, RV20, RV21, RV22: 50k log; PinSocket_1x03_P2.54mm_Vertical_LongPads
RV2, RV10: 220k log; PinSocket_2x03_P2.54mm_Vertical_LongPads_Mirrored
RV3, RV7, RV12, RV16: 47k lin; PinSocket_1x03_P2.54mm_Vertical_LongPads
RV6, RV15, RV19: 220k log; PinSocket_2x03_P2.54mm_Vertical_LongPads
SW1, SW3, SW4, SW5, SW6, SW7, SW8, SW9, SW10: SW_SPDT; PinHeader_1x02_P2.54mm_Vertical_LongPads
U1, U2, U3, U5, U6, U7, U10, U12, U13, U14, U16, U18, U20, U21, U22: TL074; DIP-14_W7.62mm_Socket_LongPads
Z1, Z3, Z4, Z7, Z8, Z13, Z17, Z18, Z20, Z24, Z25, Z28, Z29, Z30, Z31, Z34, Z36, Z37, Z39, Z43, Z44, Z45, Z46, Z47, Z48, Z52, Z53, Z56, Z60, Z61, Z64, Z65, Z66, Z68, Z69, Z70, Z71, Z74, Z77, Z78, Z81, Z82, Z83, Z84, Z85, Z88, Z89, Z90, Z91, Z92, Z93, Z96, Z101, Z102, Z103, Z104, Z105, Z106, Z107, Z108, Z110, Z111, Z114, Z115, Z116, Z117, Z118, Z119, Z120, Z121, Z122, Z123, Z124, Z125, Z126, Z127, Z128, Z129, Z130, Z131, Z132, Z133, Z138, Z139, Z141, Z147, Z148, Z149, Z153, Z159, Z160, Z161, Z162, Z163, Z164, Z165, Z166, Z167, Z168, Z169, Z170, Z171, Z172, Z173, Z174, Z182, Z183, Z184, Z185, Z186, Z187, Z188, Z195, Z196, Z197, Z198, Z199, Z200, Z205, Z208, Z209, Z214, Z215, Z216, Z217, Z218, Z219, Z220, Z221, Z222, Z223, Z231, Z233, Z234, Z235, Z236, Z263, Z264, Z265, Z266, Z267, Z268, Z269, Z270, Z271, Z272, Z273, Z274: R_0805_2012Metric_Pad1.20x1.40mm_HandSolder

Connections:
9V_GND_O: J31.1, J31.2, J31.3, J31.4
+9V_O: J31.5, J31.6
+15V_O: C66.2, C67.2, C68.2, C69.2, C74.2, C75.2, C76.2, C77.2, C78.2, C94.2, C95.2, C96.2, C97.2, C98.2, C99.2, J31.13, J31.14, U1.4 (V+), U2.4 (V+), U3.4 (V+), U5.4 (V+), U6.4 (V+), U7.4 (V+), U10.4 (V+), U12.4 (V+), U13.4 (V+), U14.4 (V+), U16.4 (V+), U18.4 (V+), U20.4 (V+), U21.4 (V+), U22.4 (V+)
-15V_O: C70.2, C71.2, C72.2, C73.2, C79.2, C80.2, C81.2, C82.2, C83.2, C104.2, C105.2, C106.2, C107.2, C108.2, C109.2, J31.7, J31.8, U1.11 (V-), U2.11 (V-), U3.11 (V-), U5.11 (V-), U6.11 (V-), U7.11 (V-), U10.11 (V-), U12.11 (V-), U13.11 (V-), U14.11 (V-), U16.11 (V-), U18.11 (V-), U20.11 (V-), U21.11 (V-), U22.11 (V-)
GND_O: C4.2, C12.2, C13.1, C14.1, C22.2, C23.1, C24.1, C32.2, C34.1, C35.1, C44.2, C45.1, C46.1, C66.1, C67.1, C68.1, C69.1, C70.1, C71.1, C72.1, C73.1, C74.1, C75.1, C76.1, C77.1, C78.1, C79.1, C80.1, C81.1, C82.1, C83.1, C94.1, C95.1, C96.1, C97.1, C98.1, C99.1, C104.1, C105.1, C106.1, C107.1, C108.1, C109.1, J1.2, J6.2, J10.2, J11.2, J18.2, J19.2, J21.2, J25.2, J26.2, J31.9, J31.10, J31.11, J31.12, R10.1, R11.1, R14.1, R23.1, R34.1, R35.1, R39.1, R47.1, R59.1, R60.1, R61.1, R74.1, R86.1, R87.1, R88.1, R100.1, R119.2, R121.2, R123.2, R133.2, R138.2, R139.2, RV19.4, Z7.2, Z8.2, Z13.2, Z20.2, Z34.2, Z36.2, Z37.2, Z43.2, Z44.2, Z45.2, Z52.2, Z53.2, Z56.2, Z64.2, Z74.2, Z77.2, Z78.2, Z88.2, Z89.2, Z90.2, Z91.2, Z96.2, Z107.2, Z108.2, Z110.2, Z111.2, Z119.2, Z120.2, Z121.2, Z122.2, Z125.2, Z132.2, Z133.2, Z138.2, Z139.2, Z147.2, Z148.2, Z149.2, Z159.2, Z160.2, Z161.2, Z169.2, Z170.2, Z171.2, Z172.2, Z173.2, Z182.2, Z185.2, Z186.2, Z187.2, Z188.2, Z198.2, Z199.2, Z200.2, Z214.2, Z215.2, Z216.2, Z218.2, Z219.2, Z220.2, Z221.2, Z222.2, Z223.2, Z233.2, Z234.2, Z235.2, Z236.2, Z265.2, Z266.2, Z269.2, Z270.2, Z271.2, Z274.2
unnamed: C4.1, H4.1
unnamed: C5.1, Z4.2
unnamed: C5.2, C6.1, R5.1
unnamed: C7.2, C8.1, R6.1
unnamed: C10.1, R17.2, R18.1
unnamed: C11.1, R19.2, R20.1
unnamed: C15.1, R22.1
unnamed: C16.1, Z48.2
unnamed: C16.2, C17.1, R28.1
unnamed: C18.2, C19.1, R29.1
unnamed: C20.1, R40.2, R41.1
unnamed: C21.1, R42.2, R43.1
unnamed: C25.1, R46.1
unnamed: C26.1, Z85.2
unnamed: C26.2, C27.1, R50.1
unnamed: C28.2, C29.1, R51.1
unnamed: C30.1, R68.2, R69.1
unnamed: C31.1, R70.2, R71.1
unnamed: C36.1, R73.1
unnamed: C38.1, Z118.2
unnamed: C38.2, C39.1, R81.1
unnamed: C40.2, C41.1, R82.1
unnamed: C42.1, R94.2, R95.1
unnamed: C43.1, R96.2, R97.1
unnamed: C47.1, R99.1
unnamed: C50.1, C51.2, R116.1
unnamed: C50.2, Z165.2
unnamed: J1.1, Z1.2, Z8.1
unnamed: J5.1, Z39.1, Z44.1
unnamed: J5.2, Z43.1
unnamed: J6.1, Z46.2, Z53.1
unnamed: J10.1, Z81.2, Z89.1
unnamed: J11.1, Z114.2, Z120.1
unnamed: J13.1, Z141.1, Z148.1
unnamed: J13.2, Z147.1
unnamed: J15.1, Z153.1, Z160.1
unnamed: J15.2, Z159.1
unnamed: J18.1, Z183.2, Z186.1
unnamed: J19.1, Z184.2, Z188.1
unnamed: J21.1, Z197.2, Z200.1
unnamed: J24.1, Z205.1, Z215.1
unnamed: J24.2, Z214.1
unnamed: J25.1, Z208.2, Z220.1
unnamed: J26.1, Z209.2, Z222.1
unnamed: J29.1, Z217.2, Z223.1
unnamed: J29.2, Z233.1
unnamed: J32.1, Z231.1, Z234.1
unnamed: J32.2, Z236.1
unnamed: R2.2, U1.14, Z17.1
unnamed: R8.2, RV3.3, U5.14, Z3.1
unnamed: R12.1, RV3.1, Z264.2
unnamed: R17.1, Z29.2
unnamed: R21.1, Z31.2
unnamed: R22.2, RV2.3
unnamed: R23.2, RV2.4
unnamed: R27.2, U1.8, Z60.1
unnamed: R31.2, RV7.3, U5.8, Z47.1
unnamed: R37.1, RV7.1, Z268.2
unnamed: R40.1, Z69.2
unnamed: R44.1, Z71.2
unnamed: R46.2, RV6.3
unnamed: R47.2, RV6.4
unnamed: R49.2, U10.14, Z82.1
unnamed: R54.1, Z83.2
unnamed: R55.2, RV12.3, U14.14, Z84.1
unnamed: R62.1, R89.1, Z141.2, Z149.1
unnamed: R63.2, U7.1, Z92.1
unnamed: R64.1, RV12.1, Z93.2
unnamed: R66.1, R92.1, Z205.2, Z216.1
unnamed: R68.1, Z104.2
unnamed: R72.1, Z106.2
unnamed: R73.2, RV10.3
unnamed: R74.2, RV10.4
unnamed: R79.2, U10.8, Z115.1
unnamed: R83.1, Z116.2
unnamed: R84.2, RV16.3, U14.8, Z117.1
unnamed: R90.2, U7.7, Z123.1
unnamed: R91.1, RV16.1, Z124.2
unnamed: R94.1, Z129.2
unnamed: R98.1, Z131.2
unnamed: R99.2, RV15.3
unnamed: R100.2, RV15.4
unnamed: R108.1, U18.14, Z162.1
unnamed: R109.2, U20.8, Z166.1
unnamed: R111.2, Z163.2
unnamed: R112.1, U21.7, Z164.1
unnamed: R115.1, U22.1, Z183.1, Z185.1
unnamed: R116.2, RV19.1, RV19.2
unnamed: R117.2, RV19.5, RV19.6
unnamed: R118.1, RV19.3, U21.8, Z167.1
unnamed: R120.2, Z196.2
unnamed: R125.1, U18.8, Z195.1
unnamed: R130.1, U21.14, Z208.1, Z219.1
unnamed: R132.1, U22.7, Z209.1, Z221.1
unnamed: R152.2, U7.14, Z263.1
unnamed: R153.1, Z18.2
unnamed: R154.2, U7.8, Z267.1
unnamed: R155.1, Z61.2
unnamed: R156.1, U20.7, Z272.1
unnamed: R157.1, Z174.2
unnamed: R1.1, RV1.1, SW1.1 (A), U1.1
unnamed: R13.1, RV1.2, RV1.3, SW1.2 (B), U1.2 (-)
unnamed: R26.1, RV5.1, SW3.1 (A), U1.7
unnamed: R38.1, RV5.2, RV5.3, SW3.2 (B), U1.6 (-)
unnamed: R48.1, RV8.1, SW4.1 (A), U10.1
unnamed: R56.1, RV8.2, RV8.3, SW4.2 (B), U10.2 (-)
unnamed: R78.1, RV14.1, SW5.1 (A), U10.7
unnamed: R85.1, RV14.2, RV14.3, SW5.2 (B), U10.6 (-)
unnamed: R107.2, R110.1, SW6.1 (A), U18.1
unnamed: R110.2, R113.2, SW6.2 (B), U18.2 (-)
unnamed: R114.2, RV20.1, SW7.1 (A), U22.14
unnamed: R122.2, RV20.2, RV20.3, SW7.2 (B), U22.13 (-)
unnamed: R124.2, R127.1, SW8.1 (A), U18.7
unnamed: R127.2, R128.2, SW8.2 (B), U18.6 (-)
unnamed: R129.2, RV21.1, SW9.1 (A), U21.1
unnamed: R136.2, RV21.2, RV21.3, SW9.2 (B), U21.2 (-)
unnamed: R131.2, RV22.1, SW10.1 (A), U22.8
unnamed: R137.2, RV22.2, RV22.3, SW10.2 (B), U22.9 (-)
unnamed: R38.2, R39.2, U1.10 (+)
unnamed: R26.2, R27.1, U1.9 (-)
unnamed: R13.2, R14.2, U1.12 (+)
unnamed: R1.2, R2.1, U1.13 (-)
unnamed: C6.2, R10.2, U2.3 (+)
unnamed: C7.1, R5.2, U2.1, U2.2 (-)
unnamed: C17.2, R34.2, U2.5 (+)
unnamed: C18.1, R28.2, U2.6 (-), U2.7
unnamed: C19.2, R35.2, U2.10 (+)
unnamed: R29.2, U2.8, U2.9 (-), Z68.1
unnamed: C8.2, R11.2, U2.12 (+)
unnamed: R6.2, U2.13 (-), U2.14, Z28.1
unnamed: U3.3 (+), U3.12 (+), Z66.2
unnamed: U3.1, U3.2 (-), Z70.1
unnamed: U3.5 (+), U3.10 (+), Z25.2
unnamed: U3.6 (-), U3.7, Z30.1
unnamed: U3.8, U3.9 (-), Z1.1, Z7.1
unnamed: U3.13 (-), U3.14, Z46.1, Z52.1
unnamed: RV3.2, U5.3 (+)
unnamed: C15.2, U5.1, U5.2 (-)
unnamed: RV7.2, U5.5 (+)
unnamed: C25.2, U5.6 (-), U5.7
unnamed: C22.1, RV6.1, RV6.2, RV6.5, RV6.6, U5.10 (+)
unnamed: R31.1, R37.2, U5.9 (-)
unnamed: C12.1, RV2.1, RV2.2, RV2.5, RV2.6, U5.12 (+)
unnamed: R8.1, R12.2, U5.13 (-)
unnamed: C13.2, R18.2, U6.3 (+)
unnamed: C10.2, R19.1, U6.1, U6.2 (-)
unnamed: C23.2, R41.2, U6.5 (+)
unnamed: C20.2, R42.1, U6.6 (-), U6.7
unnamed: C24.2, R43.2, U6.10 (+)
unnamed: C21.2, U6.8, U6.9 (-), Z65.1
unnamed: C14.2, R20.2, U6.12 (+)
unnamed: C11.2, U6.13 (-), U6.14, Z24.1
unnamed: U7.3 (+), Z107.1
unnamed: R54.2, R62.2, R63.1, R66.2, U7.2 (-)
unnamed: U7.5 (+), Z132.1
unnamed: R83.2, R89.2, R90.1, R92.2, U7.6 (-)
unnamed: U7.10 (+), Z270.1
unnamed: R154.1, R155.2, U7.9 (-)
unnamed: U7.12 (+), Z266.1
unnamed: R152.1, R153.2, U7.13 (-)
unnamed: U1.3 (+), U1.5 (+), U10.3 (+), U10.5 (+), U18.3 (+), Z39.2, Z45.1, Z217.1, Z218.1
unnamed: R85.2, R88.2, U10.10 (+)
unnamed: R78.2, R79.1, U10.9 (-)
unnamed: R56.2, R61.2, U10.12 (+)
unnamed: R48.2, R49.1, U10.13 (-)
unnamed: C27.2, R59.2, U12.3 (+)
unnamed: C28.1, R50.2, U12.1, U12.2 (-)
unnamed: C39.2, R86.2, U12.5 (+)
unnamed: C40.1, R81.2, U12.6 (-), U12.7
unnamed: C41.2, R87.2, U12.10 (+)
unnamed: R82.2, U12.8, U12.9 (-), Z128.1
unnamed: C29.2, R60.2, U12.12 (+)
unnamed: R51.2, U12.13 (-), U12.14, Z103.1
unnamed: U13.3 (+), U13.12 (+), Z127.2
unnamed: U13.1, U13.2 (-), Z130.1
unnamed: U13.5 (+), U13.10 (+), Z102.2
unnamed: U13.6 (-), U13.7, Z105.1
unnamed: U13.8, U13.9 (-), Z81.1, Z88.1
unnamed: U13.13 (-), U13.14, Z114.1, Z119.1
unnamed: RV12.2, U14.3 (+)
unnamed: C36.2, U14.1, U14.2 (-)
unnamed: RV16.2, U14.5 (+)
unnamed: C47.2, U14.6 (-), U14.7
unnamed: C44.1, RV15.1, RV15.2, RV15.5, RV15.6, U14.10 (+)
unnamed: R84.1, R91.2, U14.9 (-)
unnamed: C32.1, RV10.1, RV10.2, RV10.5, RV10.6, U14.12 (+)
unnamed: R55.1, R64.2, U14.13 (-)
unnamed: C46.2, R97.2, U16.3 (+)
unnamed: C43.2, U16.1, U16.2 (-), Z126.1
unnamed: C35.2, R71.2, U16.5 (+)
unnamed: C31.2, U16.6 (-), U16.7, Z101.1
unnamed: C34.2, R69.2, U16.10 (+)
unnamed: C30.2, R70.1, U16.8, U16.9 (-)
unnamed: C45.2, R95.2, U16.12 (+)
unnamed: C42.2, R96.1, U16.13 (-), U16.14
unnamed: U18.5 (+), Z153.2, Z161.1
unnamed: R128.1, R133.1, U18.10 (+)
unnamed: R124.1, R125.2, U18.9 (-)
unnamed: R113.1, R119.1, U18.12 (+)
unnamed: R107.1, R108.2, U18.13 (-)
unnamed: U20.3 (+), U20.12 (+), Z231.2, Z235.1, Z273.2
unnamed: U20.1, U20.2 (-), Z184.1, Z187.1
unnamed: U20.5 (+), Z271.1
unnamed: R156.2, R157.2, U20.6 (-)
unnamed: U20.10 (+), Z172.1
unnamed: R21.2, R44.2, R72.2, R98.2, R109.1, U20.9 (-)
unnamed: U20.13 (-), U20.14, Z197.1, Z199.1
unnamed: U21.3 (+), U22.10 (+), U22.12 (+), Z168.2
unnamed: U21.5 (+), Z182.1
unnamed: R111.1, R112.2, R120.1, U21.6 (-)
unnamed: C51.1, R117.1, U21.10 (+)
unnamed: R118.2, R121.1, U21.9 (-)
unnamed: R136.1, R138.1, U21.12 (+)
unnamed: R129.1, R130.2, U21.13 (-)
unnamed: R122.1, R123.1, U22.3 (+)
unnamed: R114.1, R115.2, U22.2 (-)
unnamed: R137.1, R139.1, U22.5 (+)
unnamed: R131.1, R132.2, U22.6 (-)
unnamed: Z3.2, Z4.1, Z13.1
unnamed: Z17.2, Z18.1, Z20.1
unnamed: Z24.2, Z25.1, Z34.1
unnamed: Z28.2, Z29.1, Z36.1
unnamed: Z30.2, Z31.1, Z37.1
unnamed: Z47.2, Z48.1, Z56.1
unnamed: Z60.2, Z61.1, Z64.1
unnamed: Z65.2, Z66.1, Z74.1
unnamed: Z68.2, Z69.1, Z77.1
unnamed: Z70.2, Z71.1, Z78.1
unnamed: Z82.2, Z83.1, Z90.1
unnamed: Z84.2, Z85.1, Z91.1
unnamed: Z92.2, Z93.1, Z96.1
unnamed: Z101.2, Z102.1, Z108.1
unnamed: Z103.2, Z104.1, Z110.1
unnamed: Z105.2, Z106.1, Z111.1
unnamed: Z115.2, Z116.1, Z121.1
unnamed: Z117.2, Z118.1, Z122.1
unnamed: Z123.2, Z124.1, Z125.1
unnamed: Z126.2, Z127.1, Z133.1
unnamed: Z128.2, Z129.1, Z138.1
unnamed: Z130.2, Z131.1, Z139.1
unnamed: Z162.2, Z163.1, Z169.1
unnamed: Z164.2, Z165.1, Z170.1
unnamed: Z166.2, Z173.1, Z174.1
unnamed: Z167.2, Z168.1, Z171.1
unnamed: Z195.2, Z196.1, Z198.1
unnamed: Z263.2, Z264.1, Z265.1
unnamed: Z267.2, Z268.1, Z269.1
unnamed: Z272.2, Z273.1, Z274.1

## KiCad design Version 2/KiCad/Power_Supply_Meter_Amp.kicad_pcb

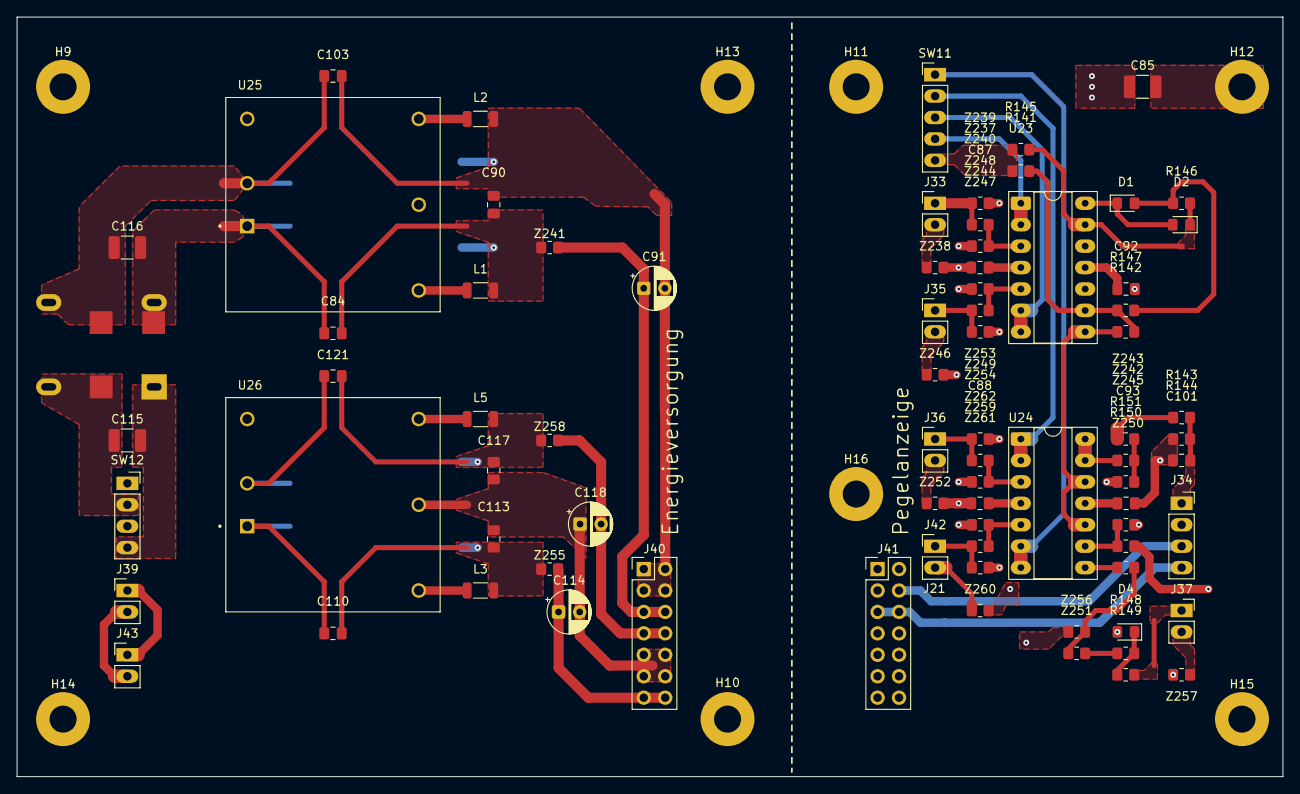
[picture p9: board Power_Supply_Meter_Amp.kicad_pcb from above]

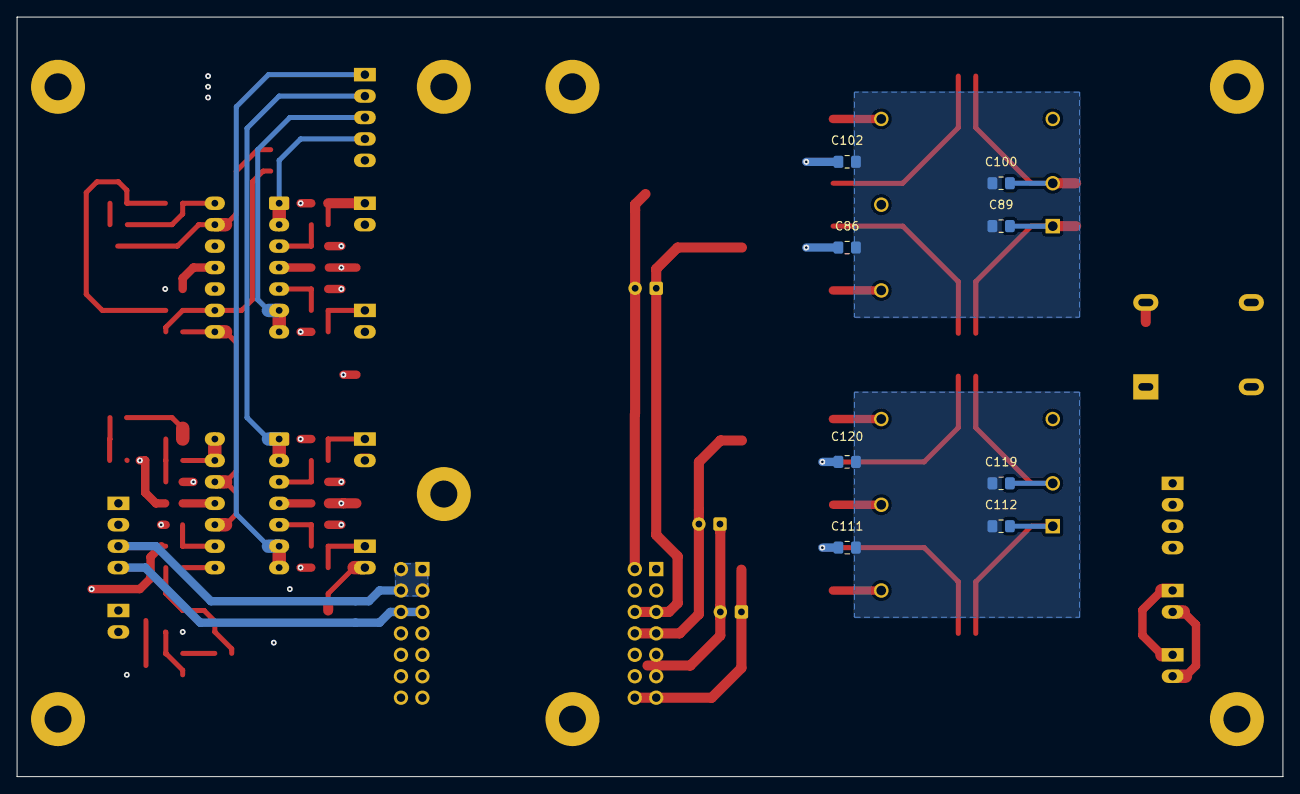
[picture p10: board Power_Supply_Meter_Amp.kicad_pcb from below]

Board: 4 copper layers, 150.0 x 90.0 mm, 95 parts (8 on the bottom side), 59 nets.

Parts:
C84, C103, C110, C121: 470p; C_0805_2012Metric_Pad1.18x1.45mm_HandSolder
C85: 10n; C_1210_3225Metric_Pad1.33x2.70mm_HandSolder
C86, C102, C111, C120: 1n; C_0805_2012Metric_Pad1.18x1.45mm_HandSolder
C87, C88, C90, C92, C93, C113, C117: 100n; C_0805_2012Metric_Pad1.18x1.45mm_HandSolder
C89, C100, C112, C119: 10n; C_0805_2012Metric_Pad1.18x1.45mm_HandSolder
C91, C114, C118: 10u; CP_Radial_D5.0mm_P2.50mm
C101: 4u7; C_0805_2012Metric_Pad1.18x1.45mm_HandSolder
C115, C116: 10u; C_1210_3225Metric_Pad1.33x2.70mm_HandSolder
D1, D2, D4: D; D_0805_2012Metric_Pad1.15x1.40mm_HandSolder
H9, H10, H11, H13, H14, H15, H16: MountingHole; MountingHole_3.2mm_M3_Pad
H12: MountingHole_Pad; MountingHole_3.2mm_M3_Pad
J33, J35, J36, J42: Pegel_In; PinHeader_1x02_P2.54mm_Vertical_LongPads
J34: VU_Meter_Out; PinSocket_1x04_P2.54mm_Vertical_LongPdas
J37: LED_Out; PinSocket_1x02_P2.54mm_Vertical_LongPads
J39: VCC_IN; PinHeader_1x02_P2.54mm_Vertical_LongPads
J40, J41: Conn_02x07_Odd_Even; PinHeader_2x07_P2.54mm_Vertical
J43: VCC_OUT; PinHeader_1x02_P2.54mm_Vertical_LongPads
L1, L2, L3, L5: Dämpfungsperle, 220 Ohm @ 100MHz, 0.5A; L_1206_3216Metric
L4: WE-SL575
R141: 20k; R_0805_2012Metric_Pad1.20x1.40mm_HandSolder
R142: 80k; R_0805_2012Metric_Pad1.20x1.40mm_HandSolder
R143, R144: 1k8; R_0805_2012Metric_Pad1.20x1.40mm_HandSolder
R145, R146, R149: 1k; R_0805_2012Metric_Pad1.20x1.40mm_HandSolder
R147, R148: 10k; R_0805_2012Metric_Pad1.20x1.40mm_HandSolder
R150: 12k; R_0805_2012Metric_Pad1.20x1.40mm_HandSolder
R151: 3k; R_0805_2012Metric_Pad1.20x1.40mm_HandSolder
SW11: SW_Rotary_1x4; PinHeader_1x05_P2.54mm_Vertical_LongPads
SW12: SW_DPST; PinSocket_1x04_P2.54mm_Vertical_LongPdas
U23, U24: TL074; DIP-14_W7.62mm_Socket_LongPads
U25: REC10K-2409; CONV_REC10K-2409SAW_H2
U26: REC10K-2415; CONV_REC10K-2415DAW_H2
Z237, Z238, Z239, Z240, Z241, Z242, Z243, Z244, Z245, Z246, Z247, Z248, Z249, Z250, Z251, Z252, Z253, Z254, Z255, Z256, Z257, Z258, Z259, Z260, Z261, Z262: R_0805_2012Metric_Pad1.20x1.40mm_HandSolder

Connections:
9V_GND_M: J34.3, J41.1, J41.2, J41.3, J41.4
9V_GND_P: C90.2, C91.2, C102.1, C103.2, J40.1, J40.2, J40.3, J40.4, L2.2
+9V_M: J34.4, J41.5, J41.6
+9V_P: C91.1, J40.5, J40.6, Z241.2
+15V_M: C87.2, C88.2, J41.13, J41.14, R150.1, U23.4 (V+), U24.4 (V+)
+15V_P: C114.1, J40.13, J40.14, Z255.2
-15V_M: C92.2, C93.2, J41.7, J41.8, U23.11 (V-), U24.11 (V-)
-15V_P: C118.2, J40.7, J40.8, Z258.2
/Pegel_Aux_Return: SW11.2, U24.1, U24.2 (-)
/Pegel_Mic_Effekt: SW11.3, U23.6 (-), U23.7
/Pegel_Post: SW11.1, U24.6 (-), U24.7
/Pegel_Pre: SW11.4, U23.1, U23.2 (-)
GND_9V_FILT: C86.1, C89.1, C100.2, C102.2
GND_15V_FILT: C111.1, C112.1, C119.2, C120.2
GND_M: C85.2, C87.1, C88.1, C92.1, C93.1, C101.2, D4.2 (A), J34.2, J41.9, J41.10, J41.11, J41.12, R144.1, R151.1, U23.10 (+), U23.12 (+), Z238.2, Z239.2, Z240.2, Z245.2, Z246.2, Z247.2, Z248.2, Z252.2, Z253.2, Z254.2, Z256.2, Z257.2, Z260.2, Z261.2, Z262.2
GND_P: C113.2, C114.2, C117.1, C118.1, J40.9, J40.10, J40.11, J40.12, U26.5 (COM)
unnamed: C84.2, C86.2, C90.1, L1.2, Z241.1
unnamed: C85.1, H12.1
unnamed: C110.2, C111.2, C113.1, L3.2, Z255.1
unnamed: C115.1, L4.1, SW12.4
unnamed: C115.2, L4.4, SW12.2
unnamed: C117.2, C120.1, C121.2, L5.2, Z258.1
unnamed: D1.2 (A), R146.2, R147.1
unnamed: D1.1 (K), D2.2 (A), U23.14
unnamed: D2.1 (K), R145.2, R146.1, U23.13 (-)
unnamed: D4.1 (K), R148.1, R149.2
unnamed: J33.1, Z237.1, Z239.1
unnamed: J33.2, Z238.1
unnamed: C101.1, J34.1, R143.2, R144.2
unnamed: J35.1, Z244.1, Z247.1
unnamed: J35.2, Z246.1
unnamed: J36.1, Z249.1, Z253.1
unnamed: J36.2, Z252.1
unnamed: J37.1, R149.1
unnamed: J37.2, Z257.1
unnamed: J39.1, J43.1, SW12.3
unnamed: J39.2, J43.2, SW12.1
unnamed: J42.1, Z259.1, Z261.1
unnamed: J42.2, Z260.1
unnamed: R141.1, R145.1, SW11.5
unnamed: R143.1, Z243.2
unnamed: R148.2, Z251.2
unnamed: U23.3 (+), Z237.2, Z240.1
unnamed: U23.5 (+), Z244.2, Z248.1
unnamed: R141.2, R142.1, R147.2, U23.9 (-)
unnamed: U24.8, Z250.1
unnamed: U24.3 (+), Z249.2, Z254.1
unnamed: U24.5 (+), Z259.2, Z262.1
unnamed: R142.2, U23.8, U24.10 (+), U24.12 (+)
unnamed: R150.2, R151.2, U24.9 (-)
unnamed: U24.13 (-), U24.14, Z242.1
unnamed: C84.1, C89.2, C110.1, C112.2, C116.1, L4.2, U25.1 (+VIN), U26.1 (+VIN)
unnamed: L1.1, U25.6 (+VOUT)
unnamed: C100.1, C103.1, C116.2, C119.1, C121.1, L4.3, U25.2 (-VIN), U26.2 (-VIN)
unnamed: L2.1, U25.4 (-VOUT)
unnamed: L3.1, U26.6 (+VOUT)
unnamed: L5.1, U26.4 (-VOUT)
unnamed: Z242.2, Z243.1, Z245.1
unnamed: Z250.2, Z251.1, Z256.1

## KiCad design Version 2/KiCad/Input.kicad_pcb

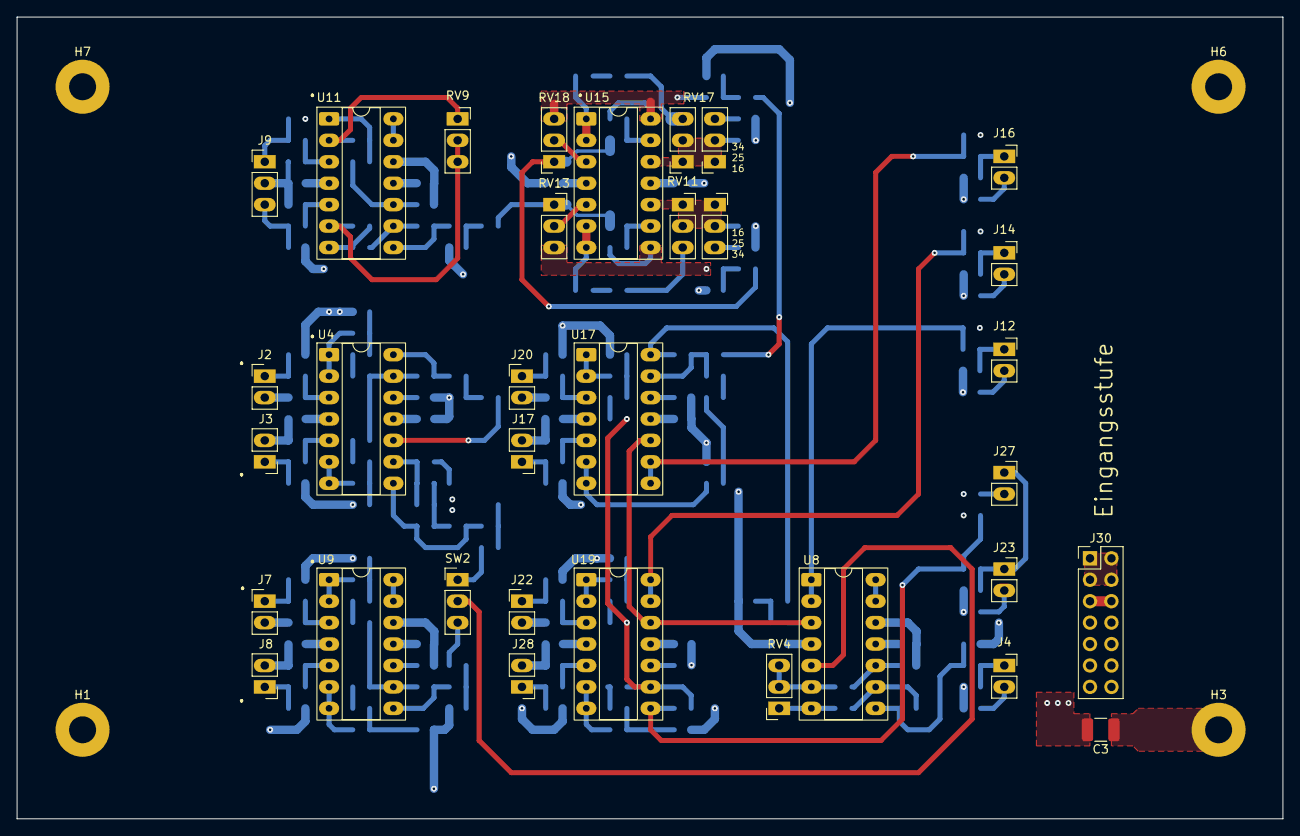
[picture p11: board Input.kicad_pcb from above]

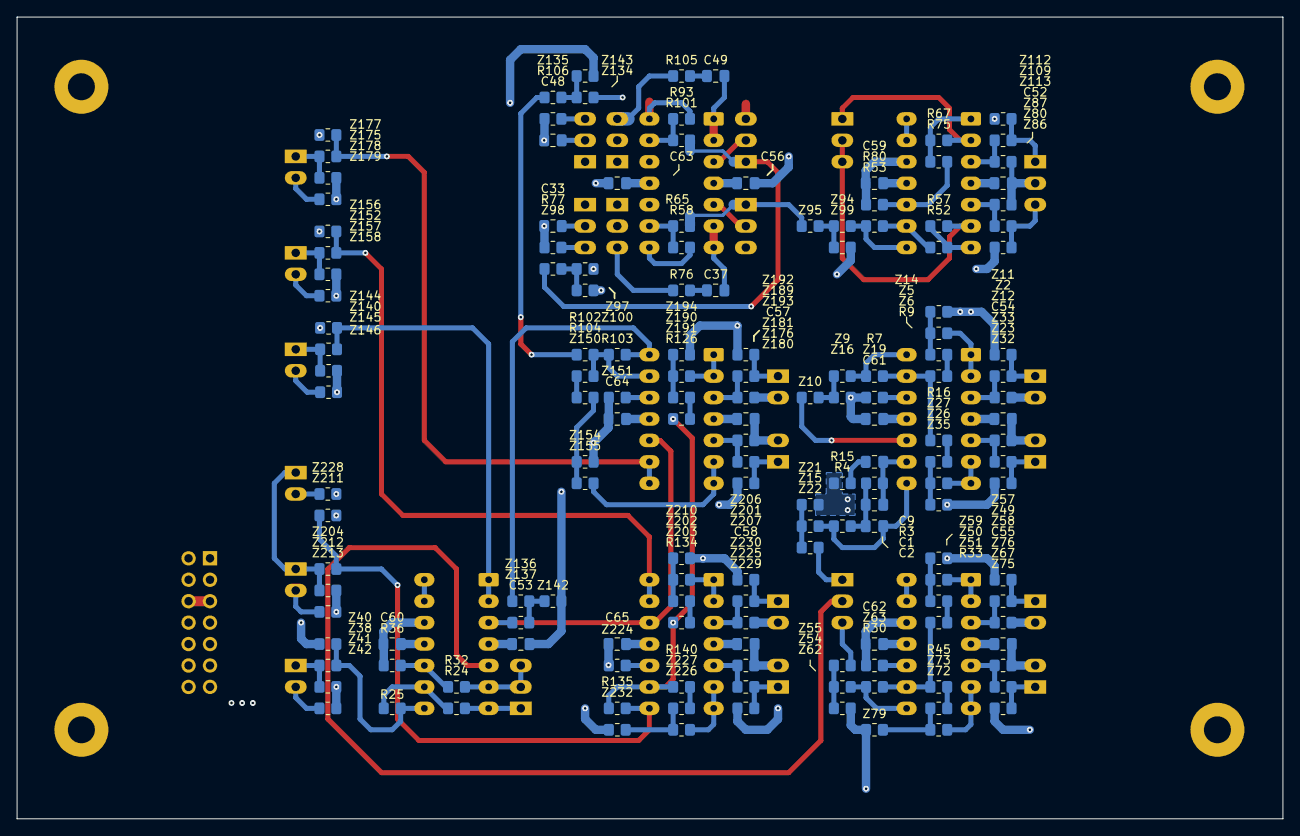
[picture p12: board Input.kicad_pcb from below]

Board: 4 copper layers, 150.0 x 95.0 mm, 190 parts (155 on the bottom side), 126 nets.

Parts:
C1: 2n2; C_0805_2012Metric_Pad1.18x1.45mm_HandSolder
C2: 10n; C_0805_2012Metric_Pad1.18x1.45mm_HandSolder
C3: 10n; C_1210_3225Metric_Pad1.33x2.70mm_HandSolder
C9: 47u; C_0805_2012Metric_Pad1.18x1.45mm_HandSolder
C33, C48: 470p; C_0805_2012Metric_Pad1.18x1.45mm_HandSolder
C37, C49: 3n; C_0805_2012Metric_Pad1.18x1.45mm_HandSolder
C52, C53, C54, C55, C56, C57, C58, C59, C60, C61, C62, C63, C64, C65: 100n; C_0805_2012Metric_Pad1.18x1.45mm_HandSolder
H1, H6, H7: MountingHole; MountingHole_3.2mm_M3_Pad
H3: MountingHole_Pad; MountingHole_3.2mm_M3_Pad
J2: R_Phono_In; PinHeader_1x02_P2.54mm_Vertical_LongPads
J3: L_Phono_In; PinHeader_1x02_P2.54mm_Vertical_LongPads
J4: Phono/Line_Out; PinSocket_1x02_P2.54mm_Vertical_LongPads
J7: R_Line_In; PinHeader_1x02_P2.54mm_Vertical_LongPads
J8: L_Line_In; PinHeader_1x02_P2.54mm_Vertical_LongPads
J9: Mic_In; PinHeader_1x03_P2.54mm_Vertical_LongPads
J12, J14, J16, J23, J27: Mic_Effekt_Out; PinSocket_1x02_P2.54mm_Vertical_LongPads
J17: AUX_RET_1; PinHeader_1x02_P2.54mm_Vertical_LongPads
J20: Effekt_In; PinHeader_1x02_P2.54mm_Vertical_LongPads
J22: AUX_RET_2; PinHeader_1x02_P2.54mm_Vertical_LongPads
J28: AUX_RET_3; PinHeader_1x02_P2.54mm_Vertical_LongPads
J30: Conn_02x07_Odd_Even; PinHeader_2x07_P2.54mm_Vertical
R3: 36k; R_0805_2012Metric_Pad1.20x1.40mm_HandSolder
R4: 390k; R_0805_2012Metric_Pad1.20x1.40mm_HandSolder
R7, R9, R16, R25, R30, R33, R45, R52, R53, R57, R67, R75, R80, R102, R103, R104, R126, R134, R135, R140: 10k; R_0805_2012Metric_Pad1.20x1.40mm_HandSolder
R15, R36: 1k; R_0805_2012Metric_Pad1.20x1.40mm_HandSolder
R24: 4k7; R_0805_2012Metric_Pad1.20x1.40mm_HandSolder
R32: 470R; R_0805_2012Metric_Pad1.20x1.40mm_HandSolder
R58, R65, R93, R101: 22k; R_0805_2012Metric_Pad1.20x1.40mm_HandSolder
R76, R77, R105, R106: 6k8; R_0805_2012Metric_Pad1.20x1.40mm_HandSolder
RV4: 50k log; PinSocket_1x03_P2.54mm_Vertical_LongPads
RV9: 10k lin; PinSocket_1x03_P2.54mm_Vertical_LongPads
RV11: 220k log; PinSocket_2x03_P2.54mm_Vertical_LongPads
RV13, RV18: 47k lin; PinSocket_1x03_P2.54mm_Vertical_LongPads
RV17: 220k log; PinSocket_2x03_P2.54mm_Vertical_LongPads_Mirrored
SW2: SW_SPDT; PinHeader_1x03_P2.54mm_Vertical_LongPads
U4, U8, U9, U11, U15, U17, U19: TL074; DIP-14_W7.62mm_Socket_LongPads
Z2, Z5, Z6, Z9, Z10, Z11, Z12, Z14, Z15, Z16, Z19, Z21, Z22, Z23, Z26, Z27, Z32, Z33, Z35, Z38, Z40, Z41, Z42, Z49, Z50, Z51, Z54, Z55, Z57, Z58, Z59, Z62, Z63, Z67, Z72, Z73, Z75, Z76, Z79, Z80, Z86, Z87, Z94, Z95, Z97, Z98, Z99, Z100, Z109, Z112, Z113, Z134, Z135, Z136, Z137, Z140, Z142, Z143, Z144, Z145, Z146, Z150, Z151, Z152, Z154, Z155, Z156, Z157, Z158, Z175, Z176, Z177, Z178, Z179, Z180, Z181, Z189, Z190, Z191, Z192, Z193, Z194, Z201, Z202, Z203, Z204, Z206, Z207, Z210, Z211, Z212, Z213, Z224, Z225, Z226, Z227, Z228, Z229, Z230, Z232: R_0805_2012Metric_Pad1.20x1.40mm_HandSolder

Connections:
9V_GND_I: J30.1, J30.2, J30.3, J30.4
+9V_I: J30.5, J30.6
+15V_I: C52.1, C53.2, C54.2, C55.2, C56.2, C57.2, C58.2, J30.13, J30.14, U4.4 (V+), U8.4 (V+), U9.4 (V+), U11.4 (V+), U15.4 (V+), U17.4 (V+), U19.4 (V+)
-15V_I: C59.2, C60.2, C61.2, C62.2, C63.2, C64.2, C65.2, J30.7, J30.8, U4.11 (V-), U8.11 (V-), U9.11 (V-), U11.11 (V-), U15.11 (V-), U17.11 (V-), U19.11 (V-)
GND_I: C3.2, C33.2, C48.2, C52.2, C53.1, C54.1, C55.1, C56.1, C57.1, C58.1, C59.1, C60.1, C61.1, C62.1, C63.1, C64.1, C65.1, J2.2, J3.2, J7.2, J8.2, J9.2, J17.2, J20.2, J22.2, J28.2, J30.9, J30.10, J30.11, J30.12, R15.1, R36.1, R77.1, R80.1, R106.1, U8.12 (+), U9.12 (+), U11.12 (+), Z11.2, Z12.2, Z14.2, Z16.2, Z19.2, Z21.2, Z32.2, Z33.2, Z35.2, Z40.2, Z41.2, Z42.2, Z57.2, Z58.2, Z59.2, Z62.2, Z63.2, Z75.2, Z76.2, Z79.2, Z86.2, Z87.2, Z99.2, Z100.2, Z112.2, Z113.2, Z142.2, Z143.1, Z144.2, Z145.2, Z146.2, Z151.2, Z154.2, Z156.2, Z157.2, Z158.2, Z177.2, Z178.2, Z179.2, Z180.2, Z181.2, Z192.2, Z193.2, Z194.2, Z206.2, Z207.2, Z210.2, Z211.2, Z212.2, Z213.2, Z224.2, Z228.2, Z229.2, Z230.2, Z232.2
unnamed: C1.2, C2.1, R3.1, R4.2
unnamed: C2.2, R4.1, U4.8, Z15.1
unnamed: C3.1, H3.1
unnamed: C9.1, R15.2
unnamed: C37.1, R76.1
unnamed: C49.1, R105.1
unnamed: J2.1, Z2.1, Z11.1
unnamed: J3.1, Z23.1, Z32.1
unnamed: J4.1, Z38.2, Z41.1
unnamed: J4.2, Z42.1
unnamed: J7.1, Z49.1, Z57.1
unnamed: J8.1, Z67.1, Z75.1
unnamed: J9.1, Z109.1, Z112.1
unnamed: J9.3, Z80.1, Z86.1
unnamed: J12.1, Z140.2, Z145.1
unnamed: J12.2, Z146.1
unnamed: J14.1, Z152.2, Z157.1
unnamed: J14.2, Z158.1
unnamed: J16.1, Z175.2, Z178.1
unnamed: J16.2, Z179.1
unnamed: J17.1, Z176.1, Z180.1
unnamed: J20.1, Z189.1, Z192.1
unnamed: J22.1, Z201.1, Z206.1
unnamed: J23.1, J27.1, Z204.2, Z212.1
unnamed: J23.2, Z213.1
unnamed: J27.2, Z228.1
unnamed: J28.1, Z225.1, Z229.1
unnamed: R7.2, U4.14, Z9.1
unnamed: R9.1, Z6.2
unnamed: R16.1, Z27.2
unnamed: R24.1, RV4.1, U8.7
unnamed: R25.2, U8.8, Z38.1, Z40.1
unnamed: R30.2, U9.8, Z54.1
unnamed: R33.1, Z51.2
unnamed: R45.1, Z73.2
unnamed: R52.1, R57.2, U11.7
unnamed: R53.1, U11.8, Z94.1
unnamed: R58.2, RV13.3, U15.8, Z97.1
unnamed: R65.1, RV13.1, Z95.2
unnamed: R67.1, R75.1, U11.1
unnamed: R76.2, RV11.3
unnamed: R77.2, RV11.4
unnamed: R93.2, RV18.3, U15.14, Z134.1
unnamed: R101.1, RV18.1, Z98.2
unnamed: R102.1, Z135.2
unnamed: R103.2, U17.14, Z136.1
unnamed: R104.1, Z150.1
unnamed: R105.2, RV17.3
unnamed: R106.2, RV17.4
unnamed: R126.2, Z191.2
unnamed: R134.2, Z203.2
unnamed: R135.1, U19.8, Z204.1, Z211.1
unnamed: R140.2, Z227.2
unnamed: SW2.1 (A), Z22.2
unnamed: SW2.2 (B), U8.5 (+)
unnamed: SW2.3 (C), Z55.2
unnamed: U4.3 (+), Z2.2, Z12.1
unnamed: U4.1, U4.2 (-), Z5.1
unnamed: U4.5 (+), Z23.2, Z33.1
unnamed: U4.6 (-), U4.7, Z26.1
unnamed: U4.10 (+), Z10.2
unnamed: C1.1, C9.2, R3.2, U4.9 (-)
unnamed: U4.12 (+), Z19.1
unnamed: R7.1, R9.2, R16.2, U4.13 (-)
unnamed: U8.1, U8.2 (-), Z140.1, Z144.1
unnamed: R32.1, RV4.2, RV4.3, U8.6 (-)
unnamed: R32.2, R36.2, U8.10 (+)
unnamed: R24.2, R25.1, U8.9 (-)
unnamed: U8.13 (-), U8.14
unnamed: U9.3 (+), Z49.2, Z58.1
unnamed: U9.1, U9.2 (-), Z50.1
unnamed: U9.5 (+), Z67.2, Z76.1
unnamed: U9.6 (-), U9.7, Z72.1
unnamed: U9.10 (+), Z63.1
unnamed: R30.1, R33.2, R45.2, U9.9 (-)
unnamed: U9.13 (-), U9.14
unnamed: U11.3 (+), Z109.2, Z113.1
unnamed: R67.2, RV9.1, U11.2 (-)
unnamed: U11.5 (+), Z80.2, Z87.1
unnamed: R57.1, RV9.2, RV9.3, U11.6 (-)
unnamed: R75.2, R80.2, U11.10 (+)
unnamed: R52.2, R53.2, U11.9 (-)
unnamed: U11.13 (-), U11.14
unnamed: RV18.2, U15.3 (+)
unnamed: C49.2, U15.1, U15.2 (-)
unnamed: RV13.2, U15.5 (+)
unnamed: C37.2, U15.6 (-), U15.7
unnamed: C33.1, RV11.1, RV11.2, RV11.5, RV11.6, U15.10 (+)
unnamed: R58.1, R65.2, U15.9 (-)
unnamed: C48.1, RV17.1, RV17.2, RV17.5, RV17.6, U15.12 (+)
unnamed: R93.1, R101.2, U15.13 (-)
unnamed: U17.3 (+), Z189.2, Z193.1
unnamed: U17.1, U17.2 (-), Z190.1
unnamed: U17.5 (+), Z176.2, Z181.1
unnamed: U17.6 (-), U17.7, Z155.2
unnamed: U8.3 (+), U17.10 (+), U19.12 (+), Z137.2
unnamed: U17.8, U17.9 (-), Z175.1, Z177.1
unnamed: U17.12 (+), Z151.1
unnamed: R102.2, R103.1, R104.2, U17.13 (-)
unnamed: U19.3 (+), Z201.2, Z207.1
unnamed: U19.1, U19.2 (-), Z202.1
unnamed: U19.5 (+), Z225.2, Z230.1
unnamed: U19.6 (-), U19.7, Z226.1
unnamed: U19.10 (+), Z224.1
unnamed: R126.1, R134.1, R135.2, R140.1, U19.9 (-)
unnamed: U19.13 (-), U19.14, Z152.1, Z156.1
unnamed: Z9.2, Z10.1, Z16.1
unnamed: Z5.2, Z6.1, Z14.1
unnamed: Z15.2, Z21.1, Z22.1
unnamed: Z26.2, Z27.1, Z35.1
unnamed: Z50.2, Z51.1, Z59.1
unnamed: Z54.2, Z55.1, Z62.1
unnamed: Z72.2, Z73.1, Z79.1
unnamed: Z94.2, Z95.1, Z99.1
unnamed: Z97.2, Z98.1, Z100.1
unnamed: Z134.2, Z135.1, Z143.2
unnamed: Z136.2, Z137.1, Z142.1
unnamed: Z150.2, Z154.1, Z155.1
unnamed: Z190.2, Z191.1, Z194.1
unnamed: Z202.2, Z203.1, Z210.1
unnamed: Z226.2, Z227.1, Z232.1

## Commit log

2025-04-16 initial upload of deflection amp 3
    [bom.csv, deflection_amp_3.csv, deflection_amp_3.kicad_pcb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]
2025-04-17 fixed BOM + DAC footprint
    [deflection_amp_3.kicad_pcb, power_supply.kicad_sch, rp2040.kicad_sch]
2025-04-17 fixed BOM + DAC footprint + regenerated files
    [bom.csv, positions.csv]
2025-04-17 cleanup part 2
    [deflection_amp_3_bom.csv, deflection_amp_3_bom_correct.csv]
2025-05-18 main supply old
    [5v_flyback.kicad_sch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]
2025-05-18 defl board upload
    [defl_amp.kicad_sch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]
2025-12-11 add main supply 3
    [BOM-main_supply_3.csv, blank.kicad_sch, deflection_amp_3.kicad_pcb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]
2026-02-02 defl 5 + mainboard 3
    [filament.kicad_sch, hv_minus.kicad_sch, main_supply_3_revised.kicad_pcb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]
2026-02-02 add new folders
    [deflection_amp_3.kicad_sch, deflection_amp_5.kicad_pcb, deflection_amp_5.kicad_sch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]
2026-02-14 add VM
    [10m.kicad_sch, BOM-main_supply_3.csv, blank.kicad_sch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]
2026-02-17 finished routing and layout
    need to update U6 stuff
    [main_supply_4_VM.kicad_pcb, main_supply_4_VM.kicad_sch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]
2026-02-17 redo PDF
    [main_supply_4_VM.kicad_sch]
2026-03-17 added defl amp 6
    [deflection_amp_6.kicad_pcb, deflection_amp_6.kicad_sch, hv_minus.kicad_sch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]
